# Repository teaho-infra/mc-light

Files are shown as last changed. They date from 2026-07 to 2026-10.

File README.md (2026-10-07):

# mc-light

感知 Claude Code agent 状态的麦当劳金拱门 "M" 指示灯。agent 干活时 M 常亮金色,等待授权时闪烁,空闲时熄灭。USB 连接,跨平台(Windows / Ubuntu)。

## 效果

| agent 状态 | 灯效 |
|---|---|
| 干活中(用户提交 / 工具执行完) | 金色常亮 |
| 等待授权(Notification) | 金色闪烁(亮 0.5s / 灭 0.5s) |
| 空闲(Stop / SessionEnd) | 熄灭 |

## 项目结构

```
mc-light/
├── firmware/            # XIAO RP2040 端 CircuitPython 固件
│   ├── boot.py          # 开启第二路 USB CDC 数据串口
│   └── code.py          # 主循环:读串口单字符,驱动 NeoPixel,45s 看门狗
├── host/                # 电脑端脚本
│   ├── mc_light.py      # hook 入口:按 VID 找串口,发送命令字符
│   ├── requirements.txt # 依赖(pyserial)
│   └── tests/           # pytest 单元测试(find_light_port / main 等)
├── hardware/            # 3D 打印外壳
│   ├── generate_m_shell.py  # 参数化生成显示器侧贴灯盒 STL
│   ├── test_generate_m_shell.py
│   └── *.stl / *.3mf    # 生成的打印件与切片文件
├── hooks/               # Claude Code hooks 配置样例
│   ├── settings.ubuntu.json
│   └── settings.windows.json
├── docs/                # 设计文档与迭代方案(superpowers specs/plans)
├── server.sh            # 辅助脚本
└── README.md
```

## 硬件

- Seeed XIAO RP2040 ×1(板载 NeoPixel RGB 灯)
- USB-C 数据线 ×1(必须是数据线,非纯充电线)
- 3D 打印:显示器右侧贴装方形灯盒。后壳容纳 XIAO RP2040,USB-C 从底部往上插入;前盖用红色半透明区域 + 黄色半透明 M 区域多色打印,两者正面齐平并透光。

### 3D 打印件

`hardware/generate_m_shell.py` 生成显示器侧贴灯盒:

| 文件 | 用途 |
|---|---|
| `hardware/mc_light_monitor_back.stl` | 后壳,背面贴双面胶,内部放 XIAO RP2040 |
| `hardware/mc_light_monitor_front_red.stl` | 前盖红色半透明区域 |
| `hardware/mc_light_monitor_front_M.stl` | 前盖黄色半透明 M 区域 |
| `hardware/mc_light_monitor_front_assembled.stl` | 前盖红黄区域装配预览 |
| `hardware/mc_light_monitor_assembled.stl` | 整体装配预览 |

多色打印时,把红色区域和黄色 M 区域作为同一个前盖的两个颜色对象合并打印。前盖正面齐平,M 不突出。装配时将 XIAO RP2040 放进后壳,USB-C 端朝下,确认线缆能从底部向上插入,再扣上前盖并把后壳贴到显示器右侧。

## 安装

### 1. 固件(板子端)
1. 给 XIAO RP2040 刷 CircuitPython。
2. 把 `neopixel.mpy` 放进 `CIRCUITPY/lib/`。
3. 复制 `firmware/boot.py`、`firmware/code.py` 到 `CIRCUITPY` 根目录,重新插拔。

### 2. 主机脚本(电脑端)
- **Windows(推荐)**:`host/mc_light.py` 用纯标准库(winreg + ctypes),不需要装任何包。
- **Ubuntu / WSL**:需要 pyserial:
  ```
  pip install -r host/requirements.txt
  ```
自测:`python3 host/mc_light.py on`(不插灯也应静默退出、返回 0)。

### 3. Claude Code / CodeBuddy hooks
把 `hooks/settings.ubuntu.json`(Ubuntu)或 `hooks/settings.windows.json`(Windows)的内容合并进你的 hook 配置文件,并把命令里的路径改成你的绝对路径。

- **Ubuntu**(Claude Code):合并进 `~/.claude/settings.json`。
- **Windows / CodeBuddy**:合并进 `~/.codebuddy/settings.json`。CodeBuddy 的 hook 命令在 Windows 上**强制用 Git Bash 执行**,配置里已用 `$CODEBUDDY_PROJECT_DIR` 环境变量定位项目,路径含空格也能正确处理。Windows 上直接用系统 `python`(已加入 PATH);若你的 python 不在 PATH,把 `python` 换成绝对路径并在两侧加引号,例如:
  ```
  "C:\\Users\\you\\AppData\\Local\\Programs\\Python\\Python312\\python.exe" "$CODEBUDDY_PROJECT_DIR/host/mc_light.py" on
  ```

> 提示:直接运行 `host/mc_light.py` 即可验证 hook 命令是否正确。CodeBuddy 的 `$CODEBUDDY_PROJECT_DIR` 只在 hook 运行时注入,命令行里手动跑要用真实路径。

## 工作原理

```
Claude Code 事件 → hook 脚本 → USB 串口(单字符 1/2/0)→ XIAO 固件 → RGB 灯
```

- `UserPromptSubmit` → 发 `1`(常亮金,干活中)
- `Notification`(仅 `permission_prompt` 授权请求,matcher 过滤)→ 发 `2`(金色闪烁,等待授权)。普通输入等待(60s 无输入的 `idle_prompt`)不触发闪烁。
- `PostToolUse`(工具执行完,含授权后)→ 发 `1`(恢复常亮)
- `Stop` / `SessionEnd` → 发 `0`(灭,空闲)

### 通信协议

主机与板子之间只有单字节字符命令,无握手、无回包:

| 字符 | 含义 | 固件行为 |
|---|---|---|
| `1` | 常亮 | 金色 (255, 180, 0) 常亮 |
| `2` | 闪烁 | 金色以 0.5s 半周期闪烁 |
| `0` | 熄灭 | 关灯 |
| 其它 | 预留(3-9) | 忽略 |

### 关键设计

- **串口选择**:`boot.py` 用 `usb_cdc.enable(console=True, data=True)` 打开两路 CDC。`host/mc_light.py` 的 `_select_data_port()` 优先 description 里的 "CDC2"/"data" 标记;Windows 上描述没有该文本时,改用 USB 接口号(`MI_00`/`MI_02`)区分——data 口接口号大。**绝不按 COM 号排序**(Windows 的 COM 号不保证顺序,`COM9` 在 `COM10` 前)。无法唯一识别时返回 None 静默退出,可用环境变量 `MC_LIGHT_PORT=COM10` 显式指定。
- **VID 自动匹配**:同时匹配 Raspberry Pi 官方 `0x2E8A` 与 Seeed 自家 `0x2886`,不硬编码端口名;别家 RP2040 板子可把 VID 加进 `XIAO_VIDS`。
- **失败静默**:找不到灯或出错时脚本静默退出、返回 0,绝不影响 Claude Code(`MC_LIGHT_DEBUG=1` 时才把错误打到 stderr)。
- **45 秒看门狗**:固件侧常亮或闪烁超时未更新自动熄灭——兜住 Ctrl+C 中断(Claude Code 中断不触发 Stop hook)。
- **非阻塞读**:固件 `serial.timeout = 0`,主循环 50ms 一拍,同时处理闪烁翻转与看门狗。

## 测试

```
pytest host/tests
pytest hardware/test_generate_m_shell.py
```

## 验收

插上灯用 Claude Code:发一句话 → M 常亮金;触发需要授权的操作 → M 闪烁;点允许 → M 恢复常亮;答完 → M 灭。不插灯时 Claude Code 完全正常。

## 排错

脚本作为 hook 时默认静默失败,不会吵到 Claude Code。手动排查加环境变量:

```
MC_LIGHT_DEBUG=1 python3 host/mc_light.py on
```

出错会打到 stderr。常见两坑:

### Ubuntu:`Permission denied: '/dev/ttyACM*'`

`/dev/ttyACM*` 属 `root:dialout`,普通用户默认没这个组。修复:

```
sudo usermod -aG dialout $USER
```

**必须重新登录一次**(注销再登录,或重启),`groups` 里才会出现 `dialout`,当前 shell 里不重登怎么试都还是 permission denied。Windows 没这个问题。

### 找不到设备 / VID 不匹配

Seeed 版 XIAO RP2040 的 USB VID 是 `0x2886`,不是 Raspberry Pi 官方的 `0x2E8A`。脚本现在两个 VID 都匹配。如果是别家 RP2040 板子(VID 不在这两个里),用下面命令看真实 VID,再加到 `host/mc_light.py` 的 `XIAO_VIDS`:

```
python3 -c "from serial.tools import list_ports; [print(p.device, hex(p.vid) if p.vid else None, p.description) for p in list_ports.comports()]"
```

Windows 上(无 pyserial)看 COM 口:

```
powershell -NoProfile -Command "Get-PnpDevice -PresentOnly | Where-Object { $_.Class -eq 'Ports' } | Format-Table FriendlyName,InstanceId -AutoSize"
```

### Windows 串口枚举与显式指定

- 板子会枚举出两个 COM 口:**console(REPL)口**和 **data 口**。脚本选 data 口。
- 若自动识别失败或插了多块同厂商板子,用环境变量显式指定:
  ```
  MC_LIGHT_PORT=COM10 MC_LIGHT_DEBUG=1 python host/mc_light.py on
  ```
- 找到的口不对时(例如灯没反应),`MC_LIGHT_DEBUG=1` 会在 stderr 打印错误;也可以逐口试:分别 `MC_LIGHT_PORT=COMx` 跑 `on`,灯亮的那口就是 data 口。

如果看到板子只出一个 COM 口(应该有两个:控制台 + 数据),说明 `firmware/boot.py` 没生效——检查它是否已复制到 `CIRCUITPY` 根目录并**断电重插**过一次(boot.py 只在上电时执行)。

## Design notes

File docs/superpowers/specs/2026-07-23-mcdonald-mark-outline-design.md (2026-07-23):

# McDonald Mark Outline Correction

## Goal

Correct the yellow mark in the monitor front-panel STL so its silhouette matches
`hardware/McDonald.jpeg` while preserving the existing 24 mm nominal width,
1.2 mm flush front-panel thickness, split-color STL workflow, and case geometry.

## Root Cause

The current `m_polygon()` buffers three center lines with a uniform stroke width.
That construction makes the arch crowns too thick, the arches too tall and
narrow, the outside shoulders too steep, and the center foot too short. A
normalized raster comparison against the supplied reference has an
intersection-over-union score of only 0.6409.

## Selected Design

Build one symmetric filled polygon from explicit outer and inner cubic Bezier
curves. The outer contour controls the overall shoulders and arch crowns. The
inner contour independently controls the two counters and center valley, so
stroke thickness can vary like the reference instead of being imposed by a
uniform buffer.

Keep the outline parameterized by `width / M_WIDTH`. Center the final polygon
from its actual bounds. Do not load the JPEG at generation time; the generated
STL must remain deterministic and self-contained.

## Alternatives Considered

- Trace the JPEG into a long fixed point list. This gives high fidelity but is
  difficult to understand, tune, and review.
- Extract the yellow mask from the JPEG every time the STL is generated. This
  keeps the raster appearance but couples production output to image-processing
  thresholds and an external asset.
- Fit independent Bezier contours. This gives comparable visual fidelity with a
  small, deterministic, maintainable geometry definition. This is selected.

## Verification

- Add a failing test for the reference width-to-height ratio.
- Add a failing test for reference-relative crown, valley, and foot positions.
- Add a failing raster-similarity test using a compact set of normalized
  reference silhouette samples rather than loading the JPEG in production.
- Retain existing volume, alignment, size, and assembly tests.
- Regenerate all affected STL outputs and confirm they are watertight.
- Render a normalized before/after overlay for visual inspection.

## Scope

Only the yellow mark geometry, its focused tests, and generated STL artifacts
change. The back shell, front thickness, red/yellow split, box dimensions, and
USB/XIAO geometry remain unchanged.

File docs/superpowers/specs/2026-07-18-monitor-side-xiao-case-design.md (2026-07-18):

# 显示器侧贴 XIAO 麦当劳灯盒设计文档

**日期**: 2026-07-18
**状态**: 设计已确认,待实现计划

## 1. 概述

本次改造将现有桌面底座式 mc-light 3D 打印件,重新建模为一个贴在电脑显示屏右侧的方形灯盒。灯盒内放入 Seeed XIAO RP2040,使用板载 NeoPixel 作为光源。USB-C 口朝下,线缆从盒子底部向上插入。

外观为麦当劳红黄色标志:前盖为红色半透明面板,黄色半透明 M 标记与前盖一体多色打印,正面齐平、不突出、不下陷。红色前盖和黄色 M 都透光。

## 2. 目标

- 方形盒体,适合用双面胶贴在显示器右边框或右侧背面。
- 容纳 Seeed XIAO RP2040,板子固定后 USB-C 端朝下。
- 底部开口允许 USB-C 插头从下往上插入。
- 前盖使用多色打印形成红色背景和黄色 M,两者都尽可能薄以便透光。
- 前盖正面平整,黄色 M 不做凸起装饰。
- 输出可打印 STL/3MF 文件,并保留组装预览文件。

## 3. 非目标

- 不做桌面底座。
- 不做外接灯珠、焊接结构或额外电路。
- 不做螺丝固定;优先使用压合、卡扣或少量胶合。
- 不追求防水、防摔或长期户外使用。

## 4. 机械结构

### 4.1 总体结构

打印件分为两大结构:

| 部件 | 功能 |
|---|---|
| 后壳 | 承载 XIAO RP2040,提供贴屏平面、侧壁和底部 USB-C 开口 |
| 一体式多色前盖 | 半透明红色面板 + 半透明黄色 M 标记,负责视觉外观和透光 |

外形建议约 `38 x 38 x 14 mm`,实现时允许根据板腔、壁厚、USB-C 插头 clearance 微调。盒体保持方形观感,边角只做小圆角或倒角以改善打印手感。

### 4.2 后壳

后壳为浅盒结构:

- 背面完全平整,预留给双面胶或纳米胶贴在显示器右侧。
- 内部竖向放置 XIAO RP2040,板子长边沿盒体竖直方向。
- USB-C 端朝下,对准底部开口。
- 板载 NeoPixel 朝向前盖,中间留扩散距离,避免灯珠贴脸造成强热点。
- 内壁优先使用浅色或反光打印材料;如果漏光明显,可改为不透光材料。

后壳内部应包含简单定位结构:

- 板腔按 XIAO RP2040 约 `21 x 17.8 mm` 外形留间隙。
- 用低矮边框、压片或限位柱限制板子晃动。
- 不压迫 USB-C 连接器、BOOT/RESET 按键或板上元件。
- 保留手动取出板子的可能性,除非后续实现中明确选择胶固定。

### 4.3 USB-C 底部开口

USB-C 从底部往上插入:

- 开口位于后壳底边中心。
- 宽度和高度应同时兼容 XIAO 板载 USB-C 母座及常见 USB-C 插头外壳。
- 插头插入后,线缆自然向下离开盒体。
- 开口不能削弱后壳底边到影响强度;必要时在开口两侧保留加强肋。

### 4.4 一体式多色透光前盖

前盖是单个几何件,但包含两个多色区域:

- 红色半透明背景区域。
- 黄色半透明 M 标记区域。

设计要求:

- 正面完全齐平。
- M 不突出、不下陷。
- 红色前盖和黄色 M 都透光。
- 厚度尽可能薄,目标 `1.0-1.5 mm`。
- M 区域和红色区域共享同一前盖厚度,依靠材料颜色区分标志。
- 前盖背面可增加浅定位边或压合边,但不能让正面产生明显台阶。

如果 STL 不适合表达多材料区域,实现时可同时输出:

- 一个装配预览模型。
- 红色区域模型。
- 黄色 M 区域模型。

多色切片软件中将红色区域和黄色区域作为同一前盖的不同颜色对象进行合并打印。

## 5. 装配方式

推荐装配顺序:

1. 将 XIAO RP2040 放入后壳,USB-C 端朝下。
2. 确认 USB-C 线可从底部向上插入并正常连接。
3. 将多色前盖压入或扣入后壳。
4. 在后壳背面贴双面胶。
5. 将灯盒贴在显示器右边框或右侧背面。

前盖与后壳之间建议使用压合结构。默认间隙取 `0.3-0.5 mm`,实际值按打印机精度调整。

## 6. 打印建议

- 前盖红色区域:红色半透明 PLA/PETG。
- 前盖 M 区域:黄色半透明 PLA/PETG。
- 后壳:红色、不透光黑色、白色或其他材料均可;若希望整体发光更均匀,后壳内侧可选白色。
- 前盖朝下打印可获得更平整的正面,但需要避免 M/红色边界处产生明显首层污染。
- 若透光不足,优先减薄前盖;若热点明显,优先增加灯珠到前盖距离或在前盖背面加轻微磨砂处理。

## 7. 输出文件

实现时更新 `hardware/generate_m_shell.py`,输出新的模型文件:

| 文件 | 用途 |
|---|---|
| `mc_light_monitor_back.stl` | 后壳打印件 |
| `mc_light_monitor_front_red.stl` | 前盖红色区域 |
| `mc_light_monitor_front_M.stl` | 前盖黄色 M 区域 |
| `mc_light_monitor_front_assembled.stl` | 前盖多色装配预览 |
| `mc_light_monitor_assembled.stl` | 整体装配预览 |

如实现工具链支持 3MF 多材料导出,可额外输出一个多材料前盖 3MF;STL 拆分仍作为通用交付物保留。

## 8. 验收标准

- XIAO RP2040 能放入后壳且不会明显晃动。
- USB-C 插头能从底部向上插入,线缆向下走线。
- 后壳背面平整,适合贴胶。
- 前盖正面为红底黄 M,表面齐平。
- 红色区域和黄色 M 区域都能透出板载 NeoPixel 的光。
- 模型导出成功,主要 STL 为 watertight 或符合切片软件可修复范围。

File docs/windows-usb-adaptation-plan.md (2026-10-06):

# Windows USB 连接适配计划

## 当前结论

项目已有 Windows hook 样例，`pyserial` 也支持 Windows COM 端口，因此通信方案可用于 Windows；但目前不能认为 Windows USB 连接已可靠适配，也没有 Windows 真机验收记录。

主要缺口：

1. `host/mc_light.py` 优先凭端口描述中的 `CDC2`/`data` 找数据口；没有这些文本时，按 `device` 字符串排序并取最后一个。Windows 的两个 CDC COM 号不保证相邻或按 console、data 顺序分配；字符串排序还会把 `COM9` 排在 `COM10` 后。此时可能写入 REPL 控制台口，灯不会响应。
2. 仅按 VID (`0x2E8A`/`0x2886`) 过滤，连接多块同厂商板子时可能选中另一块设备。
3. `hooks/settings.windows.json` 使用占位路径且没有引号；路径含空格时命令可能执行失败。它也缺少与 Ubuntu 样例一致的 `SessionEnd` 熄灯 hook。
4. 现有测试用模拟 COM 口验证基础流程，但没有覆盖 COM 号乱序、描述缺失、多设备、路径含空格，也没有 Windows + XIAO RP2040 实机测试。

## 实施步骤

1. **采集 Windows 枚举信息**：在 Windows 上接入烧录了本项目 `boot.py`/`code.py` 的 XIAO RP2040，运行 `python -m serial.tools.list_ports -v`，记录两路端口的 `device`、VID/PID、`interface`、`description`、`hwid`、`serial_number` 和 `location`。分别验证 Seeed 和 Raspberry Pi VID（若有对应硬件）。
2. **确定数据口识别规则**：优先使用可验证的 USB 接口号或固件设置的独立接口名称，结合 VID/PID、序列号/位置锁定目标板。不要把 COM 号大小当成接口顺序。若元数据不足或有多个候选口，返回“无法确定”，并提供显式端口配置（例如环境变量 `MC_LIGHT_PORT=COM10`）；不要猜测一个口。
3. **修改主机脚本和测试**：让 `find_light_port()` 采用上述规则。补充 COM9/COM10、非连续及反序 COM 号、描述为空、多块板、指定端口不存在等用例。保持 hook 失败时静默返回 0，并在 `MC_LIGHT_DEBUG=1` 下给出候选口和判定原因。
4. **修正 Windows hook 与安装文档**：给 Python 和脚本绝对路径加可靠的命令行引号，添加 `SessionEnd`，说明在 Windows 本机 Python 环境安装 `pyserial`、验证 COM 端口和启用调试的方法。说明 WSL 与 Windows 本机的端口访问需要分别配置。
5. **实机验收**：在 Windows 10/11 上断电重插板子，确认出现 console/data 两个 COM 口；运行 `on`、`wait`、`off`，分别看到常亮、闪烁、熄灭。再通过 Claude Code 触发 `UserPromptSubmit`、`Notification`、`PostToolUse`、`Stop`、`SessionEnd`。重复测试 COM 号变化、路径含空格、无设备及多设备场景，确认不会向 REPL 口写入命令。

## 完成标准

- Windows 真机上自动识别数据口，或在无法唯一识别时用显式端口配置成功连接。
- 所有上述 hook 事件触发正确灯效；断开设备或端口忙时 Claude Code 正常运行。
- Windows 相关自动化测试通过，README 给出可复现的安装、诊断和验收步骤。

参考：[CircuitPython USB CDC 文档](https://docs.circuitpython.org/en/latest/shared-bindings/usb_cdc/)（Windows COM 口顺序不保证）、[pySerial 端口枚举文档](https://pyserial.readthedocs.io/en/latest/tools.html)（端口元数据与顺序）。

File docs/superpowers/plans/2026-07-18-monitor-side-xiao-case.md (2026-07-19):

# Monitor-Side XIAO Case Implementation Plan

> **For agentic workers:** REQUIRED SUB-SKILL: Use superpowers:subagent-driven-development (recommended) or superpowers:executing-plans to implement this plan task-by-task. Steps use checkbox (`- [ ]`) syntax for tracking.

**Goal:** Replace the current desktop-base STL generator with a monitor-side square case for Seeed XIAO RP2040, including a flat multi-color translucent red/yellow front cover.

**Architecture:** Keep `hardware/generate_m_shell.py` as the single CAD generator and expose small pure functions for dimensions, McDonald's-style M geometry, back shell, front red area, front yellow M area, and assembly previews. Add Python tests that inspect mesh bounds, watertightness, and color-part alignment without needing a slicer. Export split STL files so multi-color slicers can merge the red and yellow front cover parts into one flush front face.

**Tech Stack:** Python 3, `trimesh`, `shapely`, `numpy`, pytest.

## Global Constraints

- 方形盒体,适合用双面胶贴在显示器右边框或右侧背面。
- 容纳 Seeed XIAO RP2040,板子固定后 USB-C 端朝下。
- 底部开口允许 USB-C 插头从下往上插入。
- 前盖使用多色打印形成红色背景和黄色 M,两者都尽可能薄以便透光。
- 前盖正面平整,黄色 M 不做凸起装饰。
- 红色前盖和黄色 M 都透光。
- 前盖厚度目标 `1.0-1.5 mm`。
- 不做桌面底座。
- 不做外接灯珠、焊接结构或额外电路。
- 不做螺丝固定;优先使用压合、卡扣或少量胶合。
- 输出 `mc_light_monitor_back.stl`, `mc_light_monitor_front_red.stl`, `mc_light_monitor_front_M.stl`, `mc_light_monitor_front_assembled.stl`, and `mc_light_monitor_assembled.stl`.

---

## File Structure

- Modify `hardware/generate_m_shell.py`: replace the old M lightbox + desktop base generator with the monitor-side case generator. Keep all dimensions centralized at top-level constants. Provide importable builder functions for tests.
- Create `hardware/test_generate_m_shell.py`: unit tests for critical dimensions, front-cover flush alignment, USB bottom opening, and exported file names.
- Modify `README.md`: update the 3D printing section so it describes the monitor-side box, two-part physical structure, split front STL files, and bottom-up USB-C insertion.
- Generated by running `python3 hardware/generate_m_shell.py`: `hardware/mc_light_monitor_back.stl`, `hardware/mc_light_monitor_front_red.stl`, `hardware/mc_light_monitor_front_M.stl`, `hardware/mc_light_monitor_front_assembled.stl`, `hardware/mc_light_monitor_assembled.stl`.

---

### Task 1: Add CAD Geometry Tests

**Files:**
- Create: `hardware/test_generate_m_shell.py`
- Test: `hardware/test_generate_m_shell.py`

**Interfaces:**
- Consumes: existing module import path `hardware/generate_m_shell.py`.
- Produces: tests expecting `BOX_W`, `BOX_H`, `BOX_D`, `FRONT_T`, `XIAO_W`, `XIAO_H`, `USB_OPEN_W`, `USB_OPEN_H`, `OUTPUTS`, `build_back_shell()`, `build_front_parts()`, `build_front_assembled()`, and `build_monitor_assembled()`.

- [x] **Step 1: Write the failing tests**

Create `hardware/test_generate_m_shell.py`:

```python
import importlib.util
from pathlib import Path

import pytest

MODULE_PATH = Path(__file__).with_name("generate_m_shell.py")

def load_generator():
    spec = importlib.util.spec_from_file_location("generate_m_shell", MODULE_PATH)
    module = importlib.util.module_from_spec(spec)
    spec.loader.exec_module(module)
    return module

def bounds_size(mesh):
    bounds = mesh.bounds
    return bounds[1] - bounds[0]

def test_front_parts_are_flush_and_thin():
    gen = load_generator()

    red, yellow = gen.build_front_parts()

    assert red.is_volume
    assert yellow.is_volume
    assert pytest.approx(red.bounds[:, 2].tolist(), abs=0.01) == [0.0, gen.FRONT_T]
    assert pytest.approx(yellow.bounds[:, 2].tolist(), abs=0.01) == [0.0, gen.FRONT_T]
    assert 1.0 <= gen.FRONT_T <= 1.5

def test_front_assembled_matches_square_face_size():
    gen = load_generator()

    front = gen.build_front_assembled()
    sx, sy, sz = bounds_size(front)

    assert pytest.approx(sx, abs=0.05) == gen.BOX_W
    assert pytest.approx(sy, abs=0.05) == gen.BOX_H
    assert pytest.approx(sz, abs=0.01) == gen.FRONT_T

def test_back_shell_has_bottom_usb_opening_and_xiao_clearance():
    gen = load_generator()

    back = gen.build_back_shell()
    sx, sy, sz = bounds_size(back)

    assert back.is_volume
    assert pytest.approx(sx, abs=0.05) == gen.BOX_W
    assert pytest.approx(sy, abs=0.05) == gen.BOX_H
    assert pytest.approx(sz, abs=0.05) == gen.BOX_D - gen.FRONT_T
    assert gen.BOARD_POCKET_W >= gen.XIAO_W + 1.0
    assert gen.BOARD_POCKET_H >= gen.XIAO_H + 1.0
    assert gen.USB_OPEN_W >= 12.0
    assert gen.USB_OPEN_H >= 8.0

def test_assembly_preview_contains_back_and_front_depth():
    gen = load_generator()

    assembled = gen.build_monitor_assembled()
    sx, sy, sz = bounds_size(assembled)

    assert pytest.approx(sx, abs=0.05) == gen.BOX_W
    assert pytest.approx(sy, abs=0.05) == gen.BOX_H
    assert pytest.approx(sz, abs=0.05) == gen.BOX_D

def test_output_names_match_spec():
    gen = load_generator()

    assert [name for name, _builder in gen.OUTPUTS] == [
        "mc_light_monitor_back.stl",
        "mc_light_monitor_front_red.stl",
        "mc_light_monitor_front_M.stl",
        "mc_light_monitor_front_assembled.stl",
        "mc_light_monitor_assembled.stl",
    ]
```

- [x] **Step 2: Run tests to verify they fail**

Run: `python3 -m pytest hardware/test_generate_m_shell.py -v`

Expected: FAIL with missing attributes such as `BOX_W` or `build_back_shell`.

- [x] **Step 3: Commit failing tests**

```bash
git add hardware/test_generate_m_shell.py
git commit -m "test: cover monitor case generator geometry"
```

---

### Task 2: Implement Monitor-Side Case Generator

**Files:**
- Modify: `hardware/generate_m_shell.py`
- Test: `hardware/test_generate_m_shell.py`

**Interfaces:**
- Consumes: tests from Task 1.
- Produces:
  - `build_back_shell() -> trimesh.Trimesh`
  - `build_front_parts() -> tuple[trimesh.Trimesh, trimesh.Trimesh]`
  - `build_front_assembled() -> trimesh.Trimesh`
  - `build_monitor_assembled() -> trimesh.Trimesh`
  - `OUTPUTS: list[tuple[str, Callable[[], trimesh.Trimesh]]]`

- [x] **Step 1: Replace the generator docstring and imports**

At the top of `hardware/generate_m_shell.py`, use:

```python
"""生成 mc-light 的显示器侧贴 3D 打印模型。

输出 STL(写到本脚本同目录):
  mc_light_monitor_back.stl              —— 后壳:贴屏平背 + XIAO 腔 + 底部 USB-C 开口
  mc_light_monitor_front_red.stl         —— 多色前盖红色半透明区域
  mc_light_monitor_front_M.stl           —— 多色前盖黄色半透明 M 区域
  mc_light_monitor_front_assembled.stl   —— 前盖红黄区域装配预览
  mc_light_monitor_assembled.stl         —— 整体装配预览

所有尺寸单位 mm,集中在参数区,按需修改后重跑即可。
运行:python3 hardware/generate_m_shell.py
"""
import os

import numpy as np
import trimesh
from shapely.affinity import translate as shp_translate
from shapely.geometry import MultiPolygon, Polygon, box as shp_box
```

- [x] **Step 2: Define dimensions and helpers**

Replace the old parameter block and helper functions with:

```python
# ----------------------------- 参数区 -----------------------------
BOX_W = 38.0
BOX_H = 38.0
BOX_D = 14.0
FRONT_T = 1.2
BACK_D = BOX_D - FRONT_T
WALL_T = 2.0
PRESS_CLEAR = 0.35
LIP_T = 1.0
LIP_D = 1.2

XIAO_W = 17.8
XIAO_H = 21.0
BOARD_POCKET_W = XIAO_W + 1.4
BOARD_POCKET_H = XIAO_H + 1.4
BOARD_RAIL_T = 1.0
BOARD_RAIL_H = 1.2

USB_OPEN_W = 13.5
USB_OPEN_H = 8.5
USB_OPEN_D = BACK_D + 0.6

M_WIDTH = 24.0
ARCH_R = M_WIDTH / 4.0
LEG_H = 12.0
M_HEIGHT = LEG_H + ARCH_R
CURVE_STEPS = 120

OUT_DIR = os.path.dirname(os.path.abspath(__file__))
ENGINE = "manifold"

def largest(poly):
    """buffer 后若变成 MultiPolygon,取面积最大的那块。"""
    if isinstance(poly, MultiPolygon):
        return max(poly.geoms, key=lambda g: g.area)
    return poly

def make_box(extents, center):
    mesh = trimesh.creation.box(extents=extents)
    mesh.apply_translation(center)
    return mesh
```

- [x] **Step 3: Add M and front-cover builders**

Add these functions after the helpers:

```python
def m_polygon(width=M_WIDTH):
    """返回居中的麦当劳风格 M 填充多边形,位于 XY 平面。"""
    arch_r = width / 4.0
    leg_h = LEG_H * (width / M_WIDTH)
    cx1 = arch_r
    cx2 = width - arch_r
    xs = np.linspace(0.0, width, CURVE_STEPS)
    h1 = np.sqrt(np.clip(arch_r**2 - (xs - cx1) ** 2, 0, None))
    h2 = np.sqrt(np.clip(arch_r**2 - (xs - cx2) ** 2, 0, None))
    top = leg_h + np.maximum(h1, h2)
    pts = [(0.0, 0.0)]
    pts += [(float(x), float(y)) for x, y in zip(xs, top)]
    pts += [(width, 0.0)]
    poly = Polygon(pts)
    return shp_translate(poly, xoff=-width / 2.0, yoff=-poly.bounds[3] / 2.0)

def build_front_parts():
    """返回红色背景区域和黄色 M 区域;两者 z 范围完全一致,正面齐平。"""
    face = shp_box(-BOX_W / 2.0, -BOX_H / 2.0, BOX_W / 2.0, BOX_H / 2.0)
    m_mark = m_polygon()
    red_area = face.difference(m_mark)

    red = trimesh.creation.extrude_polygon(red_area, height=FRONT_T)
    yellow = trimesh.creation.extrude_polygon(m_mark, height=FRONT_T)
    return red, yellow

def build_front_assembled():
    red, yellow = build_front_parts()
    return trimesh.util.concatenate([red, yellow])
```

- [x] **Step 4: Add back-shell builder**

Add:

```python
def build_back_shell():
    """后壳:背面平整,正面开口,底部 USB-C 开口,内部有 XIAO 限位结构。"""
    outer = make_box([BOX_W, BOX_H, BACK_D], [0, 0, BACK_D / 2.0])
    inner = make_box(
        [BOX_W - 2 * WALL_T, BOX_H - 2 * WALL_T, BACK_D - WALL_T],
        [0, 0, WALL_T + (BACK_D - WALL_T) / 2.0],
    )
    usb_cut = make_box(
        [USB_OPEN_W, WALL_T * 3.0, USB_OPEN_H],
        [0, -BOX_H / 2.0, USB_OPEN_H / 2.0],
    )
    shell = trimesh.boolean.difference([outer, inner, usb_cut], engine=ENGINE)

    rail_y_gap = BOARD_POCKET_W / 2.0 + BOARD_RAIL_T / 2.0
    rail_z = WALL_T + BOARD_POCKET_H / 2.0
    left_rail = make_box(
        [BOARD_RAIL_T, BOARD_POCKET_H, BOARD_RAIL_H],
        [-rail_y_gap, 0, rail_z],
    )
    right_rail = make_box(
        [BOARD_RAIL_T, BOARD_POCKET_H, BOARD_RAIL_H],
        [rail_y_gap, 0, rail_z],
    )
    bottom_stop = make_box(
        [BOARD_POCKET_W + 2 * BOARD_RAIL_T, BOARD_RAIL_T, BOARD_RAIL_H],
        [0, -BOARD_POCKET_H / 2.0, rail_z],
    )
    return trimesh.util.concatenate([shell, left_rail, right_rail, bottom_stop])
```

During implementation, orient dimensions so global `X` is left-right, `Y` is vertical on the displayed face, and `Z` is depth from front to back. The bottom USB opening is at negative `Y`.

- [x] **Step 5: Add assembly builders and outputs**

Add:

```python
def build_monitor_assembled():
    back = build_back_shell()
    front = build_front_assembled()
    front.apply_translation([0, 0, BACK_D])
    return trimesh.util.concatenate([back, front])

OUTPUTS = [
    ("mc_light_monitor_back.stl", build_back_shell),
    ("mc_light_monitor_front_red.stl", lambda: build_front_parts()[0]),
    ("mc_light_monitor_front_M.stl", lambda: build_front_parts()[1]),
    ("mc_light_monitor_front_assembled.stl", build_front_assembled),
    ("mc_light_monitor_assembled.stl", build_monitor_assembled),
]
```

- [x] **Step 6: Replace `main()`**

Use:

```python
def main():
    for name, builder in OUTPUTS:
        mesh = builder()
        path = os.path.join(OUT_DIR, name)
        mesh.export(path)
        wt = getattr(mesh, "is_watertight", None)
        print(
            f"{name}: {len(mesh.vertices)} verts, {len(mesh.faces)} faces, "
            f"watertight={wt}"
        )

    print("完成。后壳单独打印;前盖红色区域和黄色 M 区域作为多色同层前盖合并打印。")

if __name__ == "__main__":
    main()
```

- [x] **Step 7: Run geometry tests**

Run: `python3 -m pytest hardware/test_generate_m_shell.py -v`

Expected: PASS for all five tests.

- [x] **Step 8: Run generator and inspect exported meshes**

Run: `python3 hardware/generate_m_shell.py`

Expected output includes all five file names:

```text
mc_light_monitor_back.stl:
mc_light_monitor_front_red.stl:
mc_light_monitor_front_M.stl:
mc_light_monitor_front_assembled.stl:
mc_light_monitor_assembled.stl:
完成。后壳单独打印;前盖红色区域和黄色 M 区域作为多色同层前盖合并打印。
```

- [x] **Step 9: Commit generator changes and generated STLs**

```bash
git add hardware/generate_m_shell.py hardware/mc_light_monitor_back.stl hardware/mc_light_monitor_front_red.stl hardware/mc_light_monitor_front_M.stl hardware/mc_light_monitor_front_assembled.stl hardware/mc_light_monitor_assembled.stl
git commit -m "feat: generate monitor-side xiao case"
```

---

### Task 3: Update Hardware Documentation

**Files:**
- Modify: `README.md`
- Test: `README.md`

**Interfaces:**
- Consumes: output file names from Task 2.
- Produces: user-facing printing and assembly instructions matching the new monitor-side model.

- [x] **Step 1: Update the hardware bullet**

In `README.md`, replace:

```markdown
- 3D 打印:半透明金拱门 M 外壳(约 6cm)+ 底座,PLA 半透明/白色。M 罩在板载灯珠上方,靠打印件壁厚做光线漫射。
```

with:

```markdown
- 3D 打印:显示器右侧贴装方形灯盒。后壳容纳 XIAO RP2040,USB-C 从底部往上插入;前盖用红色半透明区域 + 黄色半透明 M 区域多色打印,两者正面齐平并透光。
```

- [x] **Step 2: Add a 3D printing subsection after the hardware list**

Insert:

```markdown
### 3D 打印件

`hardware/generate_m_shell.py` 生成显示器侧贴灯盒:

| 文件 | 用途 |
|---|---|
| `hardware/mc_light_monitor_back.stl` | 后壳,背面贴双面胶,内部放 XIAO RP2040 |
| `hardware/mc_light_monitor_front_red.stl` | 前盖红色半透明区域 |
| `hardware/mc_light_monitor_front_M.stl` | 前盖黄色半透明 M 区域 |
| `hardware/mc_light_monitor_front_assembled.stl` | 前盖红黄区域装配预览 |
| `hardware/mc_light_monitor_assembled.stl` | 整体装配预览 |

多色打印时,把红色区域和黄色 M 区域作为同一个前盖的两个颜色对象合并打印。前盖正面齐平,M 不突出。装配时将 XIAO RP2040 放进后壳,USB-C 端朝下,确认线缆能从底部向上插入,再扣上前盖并把后壳贴到显示器右侧。
```

- [x] **Step 3: Run documentation checks**

Run: `rg -n "桌面底座|mc_light_base|mc_light_M|显示器右侧|mc_light_monitor" README.md hardware/generate_m_shell.py docs/superpowers/specs/2026-07-18-monitor-side-xiao-case-design.md`

Expected: no stale README instruction telling the user to print a desktop base; monitor-side output names appear in README and generator.

- [x] **Step 4: Run full available verification**

Run: `python3 -m pytest hardware/test_generate_m_shell.py -v`

Expected: PASS.

Run: `cd host && python3 -m pytest -v`

Expected: PASS for existing host tests.

- [x] **Step 5: Commit docs**

```bash
git add README.md docs/superpowers/plans/2026-07-18-monitor-side-xiao-case.md
git commit -m "docs: document monitor-side case printing"
```

---

## Self-Review

- Spec coverage: Task 2 implements the back shell, bottom USB-C opening, XIAO pocket, flat translucent red/yellow front cover, split STL outputs, and assembly previews. Task 3 documents printing and assembly. Task 1 verifies key geometry constraints.
- Placeholder scan: no `TBD`, `TODO`, or "implement later" markers are present.
- Type consistency: tests and implementation tasks consistently use `build_back_shell`, `build_front_parts`, `build_front_assembled`, `build_monitor_assembled`, and `OUTPUTS`.

---

## 实施备注(2026-07-19)

- 已按计划实现并提交。提交顺序为 feat(生成器+STL)-> test -> docs,使每个提交都通过测试(测试依赖生成器,故生成器先于测试提交)。
- **Task 2 Step 4 偏差**:计划中限位筋高度公式 `rail_z = WALL_T + BOARD_POCKET_H / 2.0` 算得 13.2,大于 `BACK_D = 12.8`,会让筋凸出后壳前口并使 `sz ≈ BACK_D` 测试失败。已改为 `rail_z = WALL_T + BOARD_RAIL_H / 2.0`(=2.6),筋贴在内腔后壁、落在盒内 z∈[2.0, 3.2]。
- **Task 3 Step 4 已知问题(非本次范围)**:`host/tests/test_mc_light.py::test_find_light_port_returns_matching_device` 在 HEAD 即失败——测试 mock `SimpleNamespace(vid, device)` 缺少生产代码 `host/mc_light.py:22` 读取的 `description`/`interface` 属性。`host/` 未被本次改动触及,留待单独修复。

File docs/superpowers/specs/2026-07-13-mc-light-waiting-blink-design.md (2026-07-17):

# mc-light 多状态区分设计:等待授权闪烁

**日期**:2026-07-13
**状态**:已批准设计,待编写实现计划
**关联**:在 [2026-07-09 基础设计](2026-07-09-mc-light-design.md) 之上扩展

## 1. 概述

在现有两态(干活中=常亮金 / 空闲=灭)之上,新增第三态**"等待授权"=金色闪烁**。当 Claude Code 需要用户点允许(权限请求)时,M 灯从常亮切为闪烁,提示"在等你";授权后恢复常亮,回合结束后熄灭。

这用掉原设计预留的协议位 `2`,协议保持向前兼容(老固件忽略 `2`)。

## 2. 目标与非目标

### 目标
- 区分三态:干活中 / 等待授权 / 空闲,且"等待授权"用闪烁明显区别于常亮
- 授权后灯自动恢复常亮,直到回合结束才灭
- 沿用现有架构:hook 短命脚本 → 单字符 → 固件自持状态
- 硬件、3D 打印件、设备发现/静默失败逻辑一律不动

### 非目标(YAGNI)
- 呼吸/渐变闪烁(本次用硬切换亮灭,最简单)
- 更多状态颜色(出错、完成提示等,暂不做)
- 周期续命看门狗(维持现有 10 分钟兜底)

## 3. 状态与协议

| 状态 | 含义 | 协议字符 | 灯效 |
|---|---|---|---|
| 干活中 | agent 正在跑 | `1` | 常亮金 |
| 等待授权 | 需要用户点允许 | `2` | 金色闪烁(亮 0.5s / 灭 0.5s,周期 1s) |
| 空闲 | 回合结束 | `0` | 灭 |

- 单字符 ASCII,沿用原协议。`2` 为原设计预留位。
- 未知字符固件仍忽略、不崩溃 —— 向前兼容不变。

## 4. 事件映射(Claude Code hooks)

| 事件 | 发送 | 时机 | 参数 |
|---|---|---|---|
| `UserPromptSubmit` | `1` | 用户提交输入,agent 开始干活 | `on` |
| `Notification` | `2` | 需要授权 → 开始闪烁 | `wait` |
| `PostToolUse` | `1` | 工具执行完(含授权后那次)→ 恢复常亮 | `on` |
| `Stop` | `0` | 回合结束 → 灭 | `off` |

新增 `Notification`、`PostToolUse` 两个 hook。

**设计理由**:
- `Notification` 在 Claude Code 需要用户授权时触发,是"等待授权"的信号源。
- 授权后没有专门的"授权完成"事件把灯切回常亮;改用 `PostToolUse`——被授权阻塞的工具只有在用户允许后才真正执行,执行完触发 `PostToolUse` → 发 `1` 恢复常亮。正常干活时每个工具执行完也发 `1`,但对常亮态幂等、无害。
- `Notification` 不止授权时触发(空闲等待用户回话也可能发),但那种场景通常 `Stop` 已先把灯灭了,影响可忽略。

## 5. 组件改动

### 5.1 固件 `firmware/code.py`(核心改动)
主机脚本是短命的、只发一次字符即退出,因此**闪烁必须由固件自持**。

- 引入当前模式:`OFF` / `SOLID` / `BLINK`。
- 收到 `1` → SOLID(常亮金);`2` → BLINK;`0` → OFF;未知字符忽略。
- BLINK 模式:主循环用 `time.monotonic()` 每 0.5s 翻转灯亮/灭,直到收到 `1` 或 `0` 才停。
- 看门狗:SOLID 与 BLINK 都纳入现有 10 分钟兜底;超时自动灭(等授权时用户走开也会自动熄)。
- 沿用现有 `time.sleep(0.05)` 轮询主循环结构。

### 5.2 主机脚本 `host/mc_light.py`(小改动)
- 在 `COMMANDS` 字典新增 `"wait": b"2"`(现有 `on`→`b"1"`、`off`→`b"0"` 不变)。
- 其余逻辑(按 VID 发现设备、超时、静默失败返回 0)完全不动。

### 5.3 Hook 配置示例 `hooks/settings.{ubuntu,windows}.json`(补充)
- 两份示例各新增 `Notification`(跑 `mc_light.py wait`)与 `PostToolUse`(跑 `mc_light.py on`)两个 hook。
- Ubuntu 用 `python3`,Windows 用 `python`,与现有一致。

### 5.4 文档 `README.md`(补充)
- "工作原理"补上三态与新事件映射;验收步骤补一条"触发授权 → 灯闪 → 允许 → 常亮"。

## 6. 异常处理与边界

沿用原则:hook 脚本永远快速、静默、不报错退出;灯故障绝不干扰 Claude Code。新增边界:

| 情况 | 处理方式 |
|---|---|
| 等授权时用户走开 | BLINK 纳入 10 分钟看门狗,超时自动灭 |
| `Notification` 非授权场景触发 | 灯会闪,但一般 `Stop` 已先灭;可接受 |
| 收到 `2` 的老固件 | 忽略(向前兼容) |
| BLINK 期间收到 `0` | 立即灭,停止闪烁 |

## 7. 测试策略

### 7.1 固件层
- 串口发 `1`/`2`/`0`,肉眼确认 常亮 / 闪烁(亮灭各约 0.5s)/ 灭。
- 发未知字符,确认灯不变、不崩。
- BLINK 态静置,确认约 10 分钟(测试可临时改短)后自动熄灭。
- BLINK 态发 `1` 确认切常亮;发 `0` 确认立即灭。

### 7.2 主机脚本层
- 命令行跑 `mc_light.py wait`,确认灯开始闪。
- 拔灯再跑 `wait`,确认静默退出、返回码 0。

### 7.3 集成层
- 在 Claude Code 里触发一个需授权的操作(如运行命令),确认灯开始闪。
- 点允许,确认灯恢复常亮;回合答完确认灭。

### 验收标准
干活时 M 常亮金;需要授权时 M 闪烁;授权后回到常亮;答完灭。不插灯时 Claude Code 完全正常。

## 8. 交付物

- `firmware/code.py` — 新增 BLINK 模式(核心)
- `host/mc_light.py` — `COMMANDS` 新增 `wait`→`2`
- `hooks/settings.ubuntu.json` / `hooks/settings.windows.json` — 新增 `Notification` + `PostToolUse` 两个 hook
- `README.md` — 更新工作原理与验收

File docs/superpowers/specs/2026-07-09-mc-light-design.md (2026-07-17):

# mc-light 设计文档

**日期**:2026-07-09
**状态**:已批准设计,待编写实现计划

## 1. 概述

mc-light 是一个感知 Claude Code agent 运行状态的实体指示灯。灯做成麦当劳金拱门 "M" 的造型,通过 USB 连接电脑:当 Claude agent 正在干活时,M 亮起金色;agent 空闲(等待用户输入)时,M 熄灭。

面向用户:单片机小白。因此硬件与软件方案均以"最简单、最难失败、免焊接"为首要目标。

## 2. 目标与非目标

### 目标
- agent 运行时亮灯、空闲时灭灯,状态精确
- 免焊接、零常驻服务、代码量最小
- 跨平台:Windows 与 Ubuntu 同一份代码
- 灯设备缺失或故障时,绝不干扰 Claude Code 的正常使用

### 非目标(YAGNI)
- 无线 / WiFi 联网(当前不做,硬件可后期升级)
- 多状态颜色区分(当前只做两态,但协议预留扩展)
- 呼吸灯 / 渐变等需要持续通信的动画效果
- 常驻后台服务

## 3. 硬件

### 主控
**Seeed XIAO RP2040**
- 自带 USB-C 口,直接插电脑
- 板载一颗 NeoPixel RGB 灯珠(WS2812 类型),即照亮 M 的光源,无需外接、无需焊接
- 运行 CircuitPython,改代码如同改 U 盘文件
- RP2040 芯片 USB VID = `0x2E8A`

### 灯效
- 一颗板载 RGB 灯珠整体背光,照亮 3D 打印的半透明金拱门 M
- M 尺寸约 6cm,板载灯珠亮度足够
- 默认颜色:麦当劳金黄色

### 物料清单
| 物件 | 说明 |
|---|---|
| XIAO RP2040 ×1 | 主控 + 板载 RGB 灯 |
| USB-C 数据线 ×1 | 必须是数据线,非纯充电线 |
| 3D 打印:半透明 M 外壳 + 底座 | 用户自行打印,PLA 半透明/白色 |
| (可选)导光/漫射结构 | 靠打印件壁厚实现,使发光均匀 |

后期若要做更大的 M,可外接一颗大灯珠,协议不变。

## 4. 软件架构

### 数据流(单向)
```
Claude Code 事件  →  Hook 脚本(短命)  →  USB 串口  →  XIAO 固件  →  RGB 灯
```

系统三个部分,各自可独立理解与测试。

### 4.1 Claude Code Hooks(配置)
在 Claude Code settings 中注册两个 hook:
- `UserPromptSubmit`(用户提交输入,agent 开始干活)→ 运行脚本发 `1`(亮)
- `Stop`(agent 完成回复,回到空闲)→ 运行脚本发 `0`(灭)

这两个事件精确对应"运行中 vs 空闲"。

### 4.2 Hook 脚本 `mc_light.py`(电脑端)
极简 Python 脚本,接收一个参数(`on` / `off`):
1. 用 `pyserial` 的 `serial.tools.list_ports` 遍历所有串口,按 USB VID `0x2E8A` 自动锁定 XIAO 设备(不硬编码端口名)
2. 打开串口 → 写单个字符(`1` 或 `0`)→ 关闭
3. 串口操作加约 1 秒超时,绝不长时间挂起
4. 找不到设备 / 打开失败 / 写入失败 → 捕获异常,静默退出(返回码 0),不干扰 Claude Code

依赖:`pyserial`(纯 Python,跨平台)。

### 4.3 XIAO 固件 `code.py`(板子端,CircuitPython)
上电即运行的主循环:
1. 通过 `usb_cdc.data` 读**数据串口**(非 REPL 口;CircuitPython 数据串口被打开时不复位程序,故不会闪灯/掉线)
2. 读到 `1` → 灯亮(麦当劳金黄色);读到 `0` → 灯灭
3. 读到未知字符 → 忽略,不崩溃
4. 上电默认状态:灭
5. **看门狗兜底**:超过 10 分钟未再收到"亮"信号则自动熄灭,防止 Claude 异常退出(未触发 `Stop`)时灯常亮

需在 `boot.py` 中启用 `usb_cdc.data`。

### 4.4 通信协议
- 单字符 ASCII
- `1` = 亮,`0` = 灭
- 预留 `2`~`9` 给未来的多态 / 颜色扩展
- 老固件遇到不认识的字符即忽略 —— 向前兼容

## 5. 异常处理与边界情况

灯为辅助设备,绝不能因其故障干扰 Claude Code。原则:hook 脚本永远快速、静默、不报错退出。

| 情况 | 处理方式 |
|---|---|
| 灯没插 / 串口找不到 | 脚本静默退出(exit 0) |
| 串口被占用 / 写入失败 | 捕获异常,静默退出 |
| 串口设备名变化 | 按 USB VID `0x2E8A` 自动查找,不硬编码 |
| 脚本卡住 | 串口操作加约 1 秒超时 |
| 板子上电初始状态 | 默认灭 |
| Claude 异常退出未触发 Stop | 固件 10 分钟看门狗超时熄灭 |
| 收到未知字符 | 固件忽略,不崩溃 |

**看门狗取舍**:超时设 10 分钟兜底,不做周期续命(保持简单)。绝大多数 agent 回合几分钟内结束,10 分钟兜底仅在真正异常时生效。若单次任务超过 10 分钟,灯会误灭 —— 属可接受折衷。

## 6. 跨平台兼容(Windows / Ubuntu)

| 方面 | Windows | Ubuntu |
|---|---|---|
| 串口名 | `COM3`、`COM4`… | `/dev/ttyACM0`… |
| 发现方式 | 统一用 `pyserial` 的 `list_ports` 按 USB VID 匹配,同一段代码两边通用 | 同左 |
| Python 命令 | `python` / `py` | `python3` |
| 依赖安装 | `pip install pyserial` | `pip install pyserial` |

- `mc_light.py` 用 `serial.tools.list_ports` 按 VID `0x2E8A` 自动锁定设备,Windows 与 Ubuntu **同一份脚本、零改动**,并顺带解决两系统端口名都会变的问题
- spec 交付时提供两套 hook 配置示例(Windows 用 `python`,Ubuntu 用 `python3`)
- 固件 `code.py` 与操作系统无关,不受影响

## 7. 测试策略

三部分各自可独立验证。

### 7.1 固件层(XIAO `code.py`)
- 板子插电,用串口终端手动发 `1`/`0`,肉眼确认灯亮/灭
- 发未知字符,确认灯不变、不崩
- 发 `1` 后静置,确认约 10 分钟后自动熄灭(测试时可临时把超时改成 10 秒验证)

### 7.2 Hook 脚本层(`mc_light.py`)
- 命令行手动跑 `python mc_light.py on` / `off`,看灯响应
- 拔掉灯再跑,确认静默退出、返回码 0(`echo $?`)
- 串口名故意写错/被占用,确认不报错、不卡住

### 7.3 集成层(Claude Code hooks)
- 配好 hook 后,在 Claude Code 里发一句话,确认灯亮;答完确认灯灭
- 连续几轮对话,确认灯跟着起伏
- 直接关掉终端,确认灯最终(超时后)熄灭

### 验收标准
插上灯用 Claude Code 时,agent 一干活 M 就亮金色,答完就灭;不插灯时 Claude Code 完全正常。

## 8. 交付物

- `code.py` — XIAO 固件(CircuitPython)
- `boot.py` — 启用 `usb_cdc.data`
- `mc_light.py` — 电脑端 hook 脚本
- hook 配置示例(Windows + Ubuntu)
- 安装/使用说明(含 3D 打印件建议)

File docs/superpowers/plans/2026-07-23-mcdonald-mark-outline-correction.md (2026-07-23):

# McDonald Mark Outline Correction Implementation Plan

> **For agentic workers:** REQUIRED SUB-SKILL: Use superpowers:subagent-driven-development (recommended) or superpowers:executing-plans to implement this plan task-by-task. Steps use checkbox (`- [ ]`) syntax for tracking.

**Goal:** Replace the distorted uniformly buffered mark with a deterministic parametric silhouette that matches `hardware/McDonald.jpeg`.

**Architecture:** Keep `m_polygon(width)` as the only public two-dimensional mark builder. Construct one symmetric polygon from independent outer and inner cubic Bezier segments, then let the existing front-part extrusion and STL export pipeline consume it unchanged.

**Tech Stack:** Python 3, NumPy, Shapely, Trimesh, pytest.

## Global Constraints

- Keep the nominal mark width at `M_WIDTH = 24.0`.
- Keep the front panel at `FRONT_T = 1.2`.
- Keep the red/yellow front parts flush and complementary.
- Do not load `McDonald.jpeg` in production code.
- Do not change back-shell, XIAO, USB, or enclosure dimensions.

---

### Task 1: Correct and Verify the Mark Silhouette

**Files:**
- Modify: `hardware/test_generate_m_shell.py`
- Modify: `hardware/generate_m_shell.py`
- Regenerate: `hardware/mc_light_monitor_front_red.stl`
- Regenerate: `hardware/mc_light_monitor_front_M.stl`
- Regenerate: `hardware/mc_light_monitor_front_assembled.stl`
- Regenerate: `hardware/mc_light_monitor_assembled.stl`

**Interfaces:**
- Consumes: `m_polygon(width: float = M_WIDTH) -> shapely.geometry.Polygon`
- Produces: the same `m_polygon()` interface and the existing `OUTPUTS` meshes.

- [ ] **Step 1: Replace coarse logo tests with reference-derived failing assertions**

Add normalized cross-section assertions:

```python
def test_m_mark_matches_reference_proportions():
    gen = load_generator()
    mark = gen.m_polygon()
    min_x, min_y, max_x, max_y = mark.bounds
    width = max_x - min_x
    height = max_y - min_y

    assert width / height == pytest.approx(1.145, abs=0.025)

    left_outer = vertical_span(mark, min_x + width * 0.04)
    left_leg = vertical_span(mark, min_x + width * 0.125)
    left_crown = vertical_span(mark, min_x + width * 0.25)
    center_foot = vertical_span(mark, min_x + width * 0.50)

    assert left_outer == pytest.approx((min_y, min_y + height * 0.512), abs=height * 0.04)
    assert left_leg == pytest.approx((min_y, min_y + height * 0.830), abs=height * 0.04)
    assert left_crown == pytest.approx(
        (min_y + height * 0.910, min_y + height * 0.994),
        abs=height * 0.035,
    )
    assert center_foot == pytest.approx(
        (min_y + height * 0.071, min_y + height * 0.665),
        abs=height * 0.035,
    )
```

Retain the existing foot-presence assertions and add:

```python
assert mark.is_valid
assert mark.geom_type == "Polygon"
```

- [ ] **Step 2: Run the focused test and verify RED**

Run:

```bash
pytest hardware/test_generate_m_shell.py::test_m_mark_matches_reference_proportions -q
```

Expected: FAIL because the current mark has a width-to-height ratio near `1.04`
and thicker, taller crowns than the reference.

- [ ] **Step 3: Implement one explicit symmetric Bezier outline**

Keep the existing `cubic_points()` evaluator. Replace the line-buffer union with
a polygon contour defined in normalized coordinates:

```python
outer_left = cubic_points((0.0, 0.0), (0.01, 0.64), (0.14, 1.0), (0.275, 1.0), steps)
outer_valley = cubic_points((0.275, 1.0), (0.39, 1.0), (0.47, 0.72), (0.5, 0.665), steps)[1:]
outer = outer_left + outer_valley
outer += [(1.0 - x, y) for x, y in reversed(outer[:-1])]

inner_right = cubic_points((0.865, 0.0), (0.86, 0.55), (0.82, 0.91), (0.75, 0.91), steps)
inner_right += cubic_points((0.75, 0.91), (0.68, 0.91), (0.61, 0.66), (0.56, 0.55), steps)[1:]
inner_right += cubic_points((0.56, 0.55), (0.545, 0.43), (0.545, 0.16), (0.54, 0.071), steps)[1:]
inner_left = [(1.0 - x, y) for x, y in reversed(inner_right)]

normalized = outer + [(1.0, 0.0), (0.865, 0.0)] + inner_right[1:]
normalized += [(0.46, 0.071)] + inner_left[1:] + [(0.0, 0.0)]
points = [(x * width, y * width / 1.145) for x, y in normalized]
poly = Polygon(points)
```

Center the validated polygon from its actual bounds exactly as before. Remove
the no-longer-used `LineString` and `unary_union` imports.

- [ ] **Step 4: Run the focused test and tune only Bezier control points**

Run:

```bash
pytest hardware/test_generate_m_shell.py::test_m_mark_matches_reference_proportions -q
```

Expected: PASS. If a cross-section misses its tolerance, change only the
control points governing that cross-section; do not loosen the tolerance.

- [ ] **Step 5: Run the complete geometry suite**

Run:

```bash
pytest hardware/test_generate_m_shell.py -q
```

Expected: all tests pass.

- [ ] **Step 6: Regenerate STL artifacts**

Run:

```bash
python3 hardware/generate_m_shell.py
```

Expected: five files exported; every line reports `watertight=True`.

- [ ] **Step 7: Perform visual and mesh verification**

Render the normalized corrected silhouette beside the supplied reference and
confirm that the crown thickness, shoulder width, center valley, and three feet
match. Confirm the four changed front/assembly STL files have valid volumes and
the front remains `38 x 38 x 1.2 mm`.

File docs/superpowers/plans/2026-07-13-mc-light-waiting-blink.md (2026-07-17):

# mc-light 等待授权闪烁(第三态)Implementation Plan

> **For agentic workers:** REQUIRED SUB-SKILL: Use superpowers:subagent-driven-development (recommended) or superpowers:executing-plans to implement this plan task-by-task. Steps use checkbox (`- [ ]`) syntax for tracking.

**Goal:** 给 mc-light 增加第三态"等待授权=金色闪烁",授权后恢复常亮,回合结束熄灭。

**Architecture:** 沿用现有三段架构(Claude Code hook 短命脚本 → 单字符 USB 串口 → CircuitPython 固件自持状态)。新增协议字符 `2`=闪烁;固件引入 `OFF/SOLID/BLINK` 模式并在主循环里自持闪烁节奏;主机脚本 `COMMANDS` 增加 `wait`→`2`;hook 配置新增 `Notification`(发 `2`)与 `PostToolUse`(发 `1` 恢复常亮)。

**Tech Stack:** Python 3 + pyserial(主机端,pytest 测试);CircuitPython + neopixel(固件端,硬件手动测试);JSON(hook 配置)。

## Global Constraints

- 协议为单字符 ASCII:`0`=灭,`1`=常亮金,`2`=闪烁;未知字符固件必须忽略、不崩溃(向前兼容)。
- 金色 = `(255, 180, 0)`(固件中常量 `GOLD`)。
- 闪烁节奏:亮 0.5s / 灭 0.5s(周期 1s),硬切换、非渐变。
- 看门狗 = 10 分钟(`WATCHDOG_SECONDS = 600`);SOLID 与 BLINK 都受其管辖。
- hook 脚本必须永远快速、静默、返回码 0,绝不干扰 Claude Code;灯设备缺失/失败一律静默退出。
- 主机脚本发现设备按 USB VID `0x2E8A`,不硬编码端口名。
- 跨平台:Ubuntu 用 `python3`,Windows 用 `python`;`host/mc_light.py` 两平台同一份。
- 测试从 `host/` 目录运行 `python3 -m pytest`(conftest 把 `host/` 加入 sys.path)。

---

### Task 1: 主机脚本新增 `wait` 命令

**Files:**
- Modify: `host/mc_light.py:18`(`COMMANDS` 字典)
- Test: `host/tests/test_mc_light.py`

**Interfaces:**
- Consumes: 现有 `mc_light.COMMANDS`(dict[str, bytes]),`mc_light.main(argv)`。
- Produces: `mc_light.COMMANDS["wait"] == b"2"`;`main(["wait"])` 在找到设备时调用 `send_command(port, b"2")`,无设备/异常时返回 0。

- [ ] **Step 1: Write the failing tests**

在 `host/tests/test_mc_light.py` 末尾追加:

```python
def test_commands_map_wait():
    assert mc_light.COMMANDS["wait"] == b"2"

def test_main_sends_two_for_wait_when_device_found():
    with mock.patch.object(mc_light, "find_light_port", return_value="COM3"), \
         mock.patch.object(mc_light, "send_command") as send:
        assert mc_light.main(["wait"]) == 0
        send.assert_called_once_with("COM3", b"2")
```

- [ ] **Step 2: Run tests to verify they fail**

Run: `cd host && python3 -m pytest tests/test_mc_light.py::test_commands_map_wait tests/test_mc_light.py::test_main_sends_two_for_wait_when_device_found -v`
Expected: FAIL(`KeyError: 'wait'`)

- [ ] **Step 3: Add `wait` to COMMANDS**

把 `host/mc_light.py` 的 `COMMANDS` 改为:

```python
COMMANDS = {"on": b"1", "off": b"0", "wait": b"2"}
```

- [ ] **Step 4: Run full host test suite to verify pass**

Run: `cd host && python3 -m pytest -v`
Expected: PASS(含原有全部用例 + 两条新用例)

- [ ] **Step 5: Commit**

```bash
git add host/mc_light.py host/tests/test_mc_light.py
git commit -m "feat(host): add wait command sending '2' for auth-waiting state"
```

---

### Task 2: 固件新增 BLINK 模式

**Files:**
- Modify: `firmware/code.py`(整段主循环与状态变量)

**Interfaces:**
- Consumes: `GOLD`、`OFF`、`WATCHDOG_SECONDS`、`pixel`、`serial`(现有)。
- Produces: 无被其它任务依赖的接口;这是固件端行为改动。行为契约:收 `1`→常亮金,`2`→闪烁(亮 0.5s/灭 0.5s),`0`→灭;SOLID/BLINK 均受 10 分钟看门狗;未知字符忽略。

> **说明:** 固件运行在 CircuitPython 硬件上(`import board/neopixel/usb_cdc`),无法在开发机跑单元测试。本任务用**硬件手动测试**验证(见 Step 3)。改动集中在状态机与主循环。

- [ ] **Step 1: 用模式状态机重写主循环**

把 `firmware/code.py` 第 26 行起(`last_on = None` 到文件末尾)替换为:

```python
# 当前模式:"off" / "solid" / "blink"
mode = "off"
mode_since = time.monotonic()   # 进入当前(非灭)模式的时刻,用于看门狗
blink_on = False                # blink 模式下当前灯是否亮着
last_toggle = time.monotonic()  # 上次翻转时刻
BLINK_INTERVAL = 0.5            # 闪烁半周期:亮 0.5s / 灭 0.5s

def set_mode(new_mode):
    global mode, mode_since, blink_on, last_toggle
    mode = new_mode
    now = time.monotonic()
    if new_mode == "off":
        pixel[0] = OFF
    elif new_mode == "solid":
        pixel[0] = GOLD
        mode_since = now
    elif new_mode == "blink":
        blink_on = True
        pixel[0] = GOLD
        last_toggle = now
        mode_since = now

while True:
    if serial is not None and serial.in_waiting > 0:
        data = serial.read(serial.in_waiting)
        for b in data:
            ch = chr(b)
            if ch == "1":
                set_mode("solid")
            elif ch == "2":
                set_mode("blink")
            elif ch == "0":
                set_mode("off")
            # 其它字符(含预留 3-9)忽略

    now = time.monotonic()

    # 闪烁:按半周期翻转
    if mode == "blink" and (now - last_toggle) >= BLINK_INTERVAL:
        blink_on = not blink_on
        pixel[0] = GOLD if blink_on else OFF
        last_toggle = now

    # 看门狗:solid / blink 超时自动灭
    if mode in ("solid", "blink") and (now - mode_since) > WATCHDOG_SECONDS:
        set_mode("off")

    time.sleep(0.05)
```

同时删除原有 `last_on = None` 及其下的旧 `while True` 循环(被上面整体替换)。文件顶部的 imports、`GOLD`/`OFF`/`WATCHDOG_SECONDS` 常量、NeoPixel 电源与初始化、`serial = usb_cdc.data` 部分保持不变。

- [ ] **Step 2: 静态自检(语法与结构)**

Run: `python3 -c "import ast; ast.parse(open('firmware/code.py').read()); print('syntax OK')"`
Expected: 输出 `syntax OK`(仅验证语法;CircuitPython 专有模块无法在开发机导入)

- [ ] **Step 3: 硬件手动测试(把 code.py 拷到 CIRCUITPY 后)**

用串口终端向数据口逐一发送并肉眼确认:
- 发 `1` → 常亮金
- 发 `2` → 金色闪烁(亮约 0.5s、灭约 0.5s)
- 闪烁中发 `1` → 立即转常亮
- 闪烁中发 `0` → 立即灭
- 发未知字符(如 `x`)→ 灯不变、不崩
- (可选)把 `WATCHDOG_SECONDS` 临时改成 `10`,发 `2` 后静置,确认约 10 秒后自动灭;验证完改回 `600`

- [ ] **Step 4: Commit**

```bash
git add firmware/code.py
git commit -m "feat(firmware): add blink mode for auth-waiting (protocol '2')"
```

---

### Task 3: Hook 配置新增 Notification 与 PostToolUse

**Files:**
- Modify: `hooks/settings.ubuntu.json`
- Modify: `hooks/settings.windows.json`

**Interfaces:**
- Consumes: Task 1 的 `mc_light.py wait`(发 `2`)与现有 `on`(发 `1`)。
- Produces: 两份配置示例,各含 `UserPromptSubmit`/`Notification`/`PostToolUse`/`Stop` 四个 hook。

> **说明:** JSON 配置示例,无自动化测试;验证方式为 JSON 合法性 + 人工核对事件映射。

- [ ] **Step 1: 更新 Ubuntu 配置**

把 `hooks/settings.ubuntu.json` 整体替换为:

```json
{
  "hooks": {
    "UserPromptSubmit": [
      {
        "hooks": [
          { "type": "command", "command": "python3 /ABSOLUTE/PATH/mc-light/host/mc_light.py on" }
        ]
      }
    ],
    "Notification": [
      {
        "hooks": [
          { "type": "command", "command": "python3 /ABSOLUTE/PATH/mc-light/host/mc_light.py wait" }
        ]
      }
    ],
    "PostToolUse": [
      {
        "hooks": [
          { "type": "command", "command": "python3 /ABSOLUTE/PATH/mc-light/host/mc_light.py on" }
        ]
      }
    ],
    "Stop": [
      {
        "hooks": [
          { "type": "command", "command": "python3 /ABSOLUTE/PATH/mc-light/host/mc_light.py off" }
        ]
      }
    ]
  }
}
```

- [ ] **Step 2: 更新 Windows 配置**

把 `hooks/settings.windows.json` 整体替换为:

```json
{
  "hooks": {
    "UserPromptSubmit": [
      {
        "hooks": [
          { "type": "command", "command": "python C:\\ABSOLUTE\\PATH\\mc-light\\host\\mc_light.py on" }
        ]
      }
    ],
    "Notification": [
      {
        "hooks": [
          { "type": "command", "command": "python C:\\ABSOLUTE\\PATH\\mc-light\\host\\mc_light.py wait" }
        ]
      }
    ],
    "PostToolUse": [
      {
        "hooks": [
          { "type": "command", "command": "python C:\\ABSOLUTE\\PATH\\mc-light\\host\\mc_light.py on" }
        ]
      }
    ],
    "Stop": [
      {
        "hooks": [
          { "type": "command", "command": "python C:\\ABSOLUTE\\PATH\\mc-light\\host\\mc_light.py off" }
        ]
      }
    ]
  }
}
```

- [ ] **Step 3: 验证两份 JSON 合法**

Run: `python3 -c "import json; json.load(open('hooks/settings.ubuntu.json')); json.load(open('hooks/settings.windows.json')); print('json OK')"`
Expected: 输出 `json OK`

- [ ] **Step 4: Commit**

```bash
git add hooks/settings.ubuntu.json hooks/settings.windows.json
git commit -m "feat(hooks): add Notification (blink) and PostToolUse (solid) hooks"
```

---

### Task 4: 更新 README

**Files:**
- Modify: `README.md`(工作原理、事件映射、验收)

**Interfaces:**
- Consumes: 上述三态协议与四个 hook 事件。
- Produces: 文档,无测试。

- [ ] **Step 1: 更新"工作原理"事件映射段**

把 `README.md` 中"工作原理"下的事件列表(现为 `UserPromptSubmit → 1` / `Stop → 0` 两条)替换为:

```markdown
- `UserPromptSubmit` → 发 `1`(常亮金,干活中)
- `Notification`(需要授权)→ 发 `2`(金色闪烁,等待授权)
- `PostToolUse`(工具执行完,含授权后)→ 发 `1`(恢复常亮)
- `Stop` → 发 `0`(灭,空闲)
- 脚本按 USB VID `0x2E8A` 自动找设备,不硬编码端口名。
- 找不到灯或出错时脚本静默退出,绝不影响 Claude Code。
- 固件 10 分钟看门狗:常亮或闪烁超时未更新则自动熄灭。
```

- [ ] **Step 2: 更新顶部一句话描述**

把 `README.md` 第 3 行改为:

```markdown
感知 Claude Code agent 状态的麦当劳金拱门 "M" 指示灯。agent 干活时 M 常亮金色,等待授权时闪烁,空闲时熄灭。USB 连接,跨平台(Windows / Ubuntu)。
```

- [ ] **Step 3: 更新"验收"段**

把 `README.md` 末尾"验收"段落正文替换为:

```markdown
插上灯用 Claude Code:发一句话 → M 常亮金;触发需要授权的操作 → M 闪烁;点允许 → M 恢复常亮;答完 → M 灭。不插灯时 Claude Code 完全正常。
```

- [ ] **Step 4: Commit**

```bash
git add README.md
git commit -m "docs: document three-state behavior and new hooks"
```

---

## Self-Review

**1. Spec coverage:**
- 协议 `2`=闪烁 → Task 1(主机)+ Task 2(固件)✓
- 事件映射 `Notification`/`PostToolUse` → Task 3 ✓
- 固件 BLINK 模式 + 看门狗纳入 → Task 2 ✓
- 主机 `COMMANDS` 加 `wait` → Task 1 ✓
- README 更新 → Task 4 ✓
- 硬件/3D 打印件/设备发现逻辑不动 → 计划中未触碰,符合非目标 ✓

**2. Placeholder scan:** 无 TBD/TODO;每个代码步骤含完整代码;JSON/固件全文给出。✓

**3. Type consistency:** `COMMANDS["wait"] == b"2"` 在 Task 1 定义、Task 3 引用一致;固件模式字符串 `"off"/"solid"/"blink"` 与 `set_mode` 全程一致;`GOLD/OFF/WATCHDOG_SECONDS/BLINK_INTERVAL` 命名一致。✓

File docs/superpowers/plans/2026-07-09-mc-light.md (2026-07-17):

# mc-light Implementation Plan

> **For agentic workers:** REQUIRED SUB-SKILL: Use superpowers:subagent-driven-development (recommended) or superpowers:executing-plans to implement this plan task-by-task. Steps use checkbox (`- [ ]`) syntax for tracking.

**Goal:** Build a USB-connected "麦当劳金拱门 M" indicator light that turns gold while a Claude Code agent is working and off when idle.

**Architecture:** Claude Code hooks fire short-lived Python scripts that write a single ASCII char over USB serial to a Seeed XIAO RP2040. CircuitPython firmware on the board reads the char and sets its onboard NeoPixel. Host script is unit-testable (mocked serial); firmware is hardware-tested manually.

**Tech Stack:** Python 3 + pyserial (host), CircuitPython + neopixel + usb_cdc (firmware), pytest (host tests).

## Global Constraints

- Host script must NEVER disrupt Claude Code: on any error (no device, port busy, write fail) it exits 0 silently.
- Never hardcode the serial port name — discover by USB VID `0x2E8A` (RP2040).
- Serial operations use a ~1 second timeout; never hang.
- Protocol: single ASCII char. `1` = on, `0` = off. `2`–`9` reserved; unknown chars ignored by firmware (forward-compatible).
- Firmware power-on default: OFF.
- Firmware watchdog: auto-off after 600 seconds (10 min) without a new "on".
- Light color when on: McDonald's gold `(255, 180, 0)`.
- Cross-platform: one host script for Windows and Ubuntu (VID-based discovery); only the `python` vs `python3` invocation differs, handled in hook config.

---

### Task 1: Host — discover the light's serial port by USB VID

**Files:**
- Create: `host/mc_light.py`
- Create: `host/requirements.txt`
- Test: `host/tests/test_mc_light.py`

**Interfaces:**
- Consumes: nothing (first task).
- Produces: `find_light_port(vid: int = 0x2E8A) -> str | None` — returns the port device name (e.g. `"COM3"` / `"/dev/ttyACM0"`) of the first serial port whose USB VID matches, else `None`. Module constant `XIAO_VID = 0x2E8A`.

- [ ] **Step 1: Create requirements file**

Create `host/requirements.txt`:

```
pyserial>=3.5
pytest>=7.0
```

Install: `pip install -r host/requirements.txt`

- [ ] **Step 2: Write the failing test**

Create `host/tests/test_mc_light.py`:

```python
from types import SimpleNamespace
from unittest import mock

import mc_light

def _port(vid, device):
    return SimpleNamespace(vid=vid, device=device)

def test_find_light_port_returns_matching_device():
    ports = [_port(0x1234, "COM1"), _port(0x2E8A, "COM3")]
    with mock.patch.object(mc_light.list_ports, "comports", return_value=ports):
        assert mc_light.find_light_port() == "COM3"

def test_find_light_port_returns_none_when_no_match():
    ports = [_port(0x1234, "COM1"), _port(None, "COM2")]
    with mock.patch.object(mc_light.list_ports, "comports", return_value=ports):
        assert mc_light.find_light_port() is None
```

- [ ] **Step 3: Run test to verify it fails**

Run: `cd host && python -m pytest tests/test_mc_light.py -v`
Expected: FAIL — `ModuleNotFoundError: No module named 'mc_light'` (or `AttributeError` on `find_light_port`).

- [ ] **Step 4: Write minimal implementation**

Create `host/mc_light.py`:

```python
"""mc-light host hook script: send on/off over USB serial to the XIAO RP2040."""
import sys

import serial
from serial.tools import list_ports

XIAO_VID = 0x2E8A

def find_light_port(vid=XIAO_VID):
    """Return the device name of the first serial port matching `vid`, else None."""
    for port in list_ports.comports():
        if port.vid == vid:
            return port.device
    return None
```

- [ ] **Step 5: Run test to verify it passes**

Run: `cd host && python -m pytest tests/test_mc_light.py -v`
Expected: PASS (2 passed).

- [ ] **Step 6: Commit**

```bash
git add host/mc_light.py host/requirements.txt host/tests/test_mc_light.py
git commit -m "feat(host): discover XIAO light port by USB VID"
```

---

### Task 2: Host — send a command byte over serial with timeout

**Files:**
- Modify: `host/mc_light.py`
- Test: `host/tests/test_mc_light.py`

**Interfaces:**
- Consumes: `find_light_port` (Task 1).
- Produces: `send_command(port: str, byte: bytes, timeout: float = 1.0) -> None` — opens the serial port with read+write timeouts, writes `byte`, closes. Raises on failure (caller decides how to handle). Module constant `COMMANDS = {"on": b"1", "off": b"0"}`.

- [ ] **Step 1: Write the failing test**

Append to `host/tests/test_mc_light.py`:

```python
def test_send_command_opens_with_timeouts_and_writes():
    fake_ser = mock.MagicMock()
    fake_ser.__enter__.return_value = fake_ser
    with mock.patch.object(mc_light.serial, "Serial", return_value=fake_ser) as ctor:
        mc_light.send_command("COM3", b"1", timeout=1.0)
    ctor.assert_called_once_with("COM3", timeout=1.0, write_timeout=1.0)
    fake_ser.write.assert_called_once_with(b"1")

def test_commands_map_on_off():
    assert mc_light.COMMANDS["on"] == b"1"
    assert mc_light.COMMANDS["off"] == b"0"
```

- [ ] **Step 2: Run test to verify it fails**

Run: `cd host && python -m pytest tests/test_mc_light.py -v`
Expected: FAIL — `AttributeError: module 'mc_light' has no attribute 'send_command'`.

- [ ] **Step 3: Write minimal implementation**

Add to `host/mc_light.py` (after `find_light_port`):

```python
COMMANDS = {"on": b"1", "off": b"0"}

def send_command(port, byte, timeout=1.0):
    """Open `port`, write `byte`, close. Raises on failure."""
    with serial.Serial(port, timeout=timeout, write_timeout=timeout) as ser:
        ser.write(byte)
```

- [ ] **Step 4: Run test to verify it passes**

Run: `cd host && python -m pytest tests/test_mc_light.py -v`
Expected: PASS (4 passed).

- [ ] **Step 5: Commit**

```bash
git add host/mc_light.py host/tests/test_mc_light.py
git commit -m "feat(host): send command byte over serial with timeout"
```

---

### Task 3: Host — CLI entry point that never disrupts Claude Code

**Files:**
- Modify: `host/mc_light.py`
- Test: `host/tests/test_mc_light.py`

**Interfaces:**
- Consumes: `find_light_port`, `send_command`, `COMMANDS`.
- Produces: `main(argv: list[str] | None = None) -> int` — parses `argv[0]` (`"on"`/`"off"`); ALWAYS returns 0. Unknown arg → return 0 (no serial). No device → return 0 (no send). `send_command` raises → swallow, return 0. `__main__` calls `sys.exit(main())`.

- [ ] **Step 1: Write the failing test**

Append to `host/tests/test_mc_light.py`:

```python
def test_main_unknown_arg_returns_0_and_skips_serial():
    with mock.patch.object(mc_light, "find_light_port") as find:
        assert mc_light.main(["bogus"]) == 0
        find.assert_not_called()

def test_main_no_arg_returns_0():
    assert mc_light.main([]) == 0

def test_main_no_device_returns_0_and_skips_send():
    with mock.patch.object(mc_light, "find_light_port", return_value=None), \
         mock.patch.object(mc_light, "send_command") as send:
        assert mc_light.main(["on"]) == 0
        send.assert_not_called()

def test_main_sends_correct_byte_when_device_found():
    with mock.patch.object(mc_light, "find_light_port", return_value="COM3"), \
         mock.patch.object(mc_light, "send_command") as send:
        assert mc_light.main(["off"]) == 0
        send.assert_called_once_with("COM3", b"0")

def test_main_returns_0_when_send_raises():
    with mock.patch.object(mc_light, "find_light_port", return_value="COM3"), \
         mock.patch.object(mc_light, "send_command", side_effect=OSError("busy")):
        assert mc_light.main(["on"]) == 0
```

- [ ] **Step 2: Run test to verify it fails**

Run: `cd host && python -m pytest tests/test_mc_light.py -v`
Expected: FAIL — `AttributeError: module 'mc_light' has no attribute 'main'`.

- [ ] **Step 3: Write minimal implementation**

Add to end of `host/mc_light.py`:

```python
def main(argv=None):
    argv = argv if argv is not None else sys.argv[1:]
    if not argv or argv[0] not in COMMANDS:
        return 0
    byte = COMMANDS[argv[0]]
    port = find_light_port()
    if port is None:
        return 0
    try:
        send_command(port, byte)
    except Exception:
        pass
    return 0

if __name__ == "__main__":
    sys.exit(main())
```

- [ ] **Step 4: Run test to verify it passes**

Run: `cd host && python -m pytest tests/test_mc_light.py -v`
Expected: PASS (9 passed).

- [ ] **Step 5: Manual smoke test (no hardware needed)**

Run: `cd host && python mc_light.py on; echo "exit=$?"`
Expected: prints `exit=0` even with no light plugged in (silent, no traceback).

- [ ] **Step 6: Commit**

```bash
git add host/mc_light.py host/tests/test_mc_light.py
git commit -m "feat(host): CLI entry point that always exits 0"
```

---

### Task 4: Firmware — boot.py + code.py for the XIAO RP2040

**Files:**
- Create: `firmware/boot.py`
- Create: `firmware/code.py`

**Interfaces:**
- Consumes: the single-char protocol from Global Constraints.
- Produces: firmware that reads `usb_cdc.data` and drives the onboard NeoPixel. No unit tests (CircuitPython hardware modules); manual hardware tests below (spec §7.1).

> **Note:** These files are copied onto the board's `CIRCUITPY` USB drive; they run on the board, not on the host. Requires CircuitPython installed on the XIAO RP2040 and the `neopixel` library present in `CIRCUITPY/lib/`.

- [ ] **Step 1: Create boot.py (enable the data serial port)**

Create `firmware/boot.py`:

```python
# 启用第二路 USB 串口(数据口),打开它不会复位正在运行的程序
import usb_cdc

usb_cdc.enable(console=True, data=True)
```

- [ ] **Step 2: Create code.py (main loop)**

Create `firmware/code.py`:

```python
# mc-light 固件:读 USB 数据串口的单字符,驱动板载 NeoPixel
import time

import board
import digitalio
import neopixel
import usb_cdc

GOLD = (255, 180, 0)          # 麦当劳金黄色
OFF = (0, 0, 0)
WATCHDOG_SECONDS = 600        # 10 分钟兜底熄灭

# XIAO RP2040 板载 NeoPixel 需要先给 NEOPIXEL_POWER 供电
power = digitalio.DigitalInOut(board.NEOPIXEL_POWER)
power.direction = digitalio.Direction.OUTPUT
power.value = True

pixel = neopixel.NeoPixel(board.NEOPIXEL, 1)
pixel.brightness = 0.5
pixel[0] = OFF                # 上电默认:灭

serial = usb_cdc.data         # 数据口(非 REPL 控制台口)
if serial is not None:
    serial.timeout = 0        # 非阻塞读

last_on = None                # 上次点亮时刻;None 表示当前熄灭

while True:
    if serial is not None and serial.in_waiting > 0:
        data = serial.read(serial.in_waiting)
        for b in data:
            ch = chr(b)
            if ch == "1":
                pixel[0] = GOLD
                last_on = time.monotonic()
            elif ch == "0":
                pixel[0] = OFF
                last_on = None
            # 其它字符(含预留 2-9)忽略
    # 看门狗:亮着且超时则自动熄灭
    if last_on is not None and (time.monotonic() - last_on) > WATCHDOG_SECONDS:
        pixel[0] = OFF
        last_on = None
    time.sleep(0.05)
```

- [ ] **Step 3: Deploy to the board**

- Flash CircuitPython onto the XIAO RP2040 (drag the UF2 while holding BOOT).
- Copy `neopixel.mpy` (+ its deps) into `CIRCUITPY/lib/` from the CircuitPython library bundle.
- Copy `firmware/boot.py` and `firmware/code.py` to the `CIRCUITPY` drive root.
- Eject and replug so `boot.py` takes effect (data serial port appears).

- [ ] **Step 4: Manual hardware test — on/off (spec §7.1)**

Open a serial terminal on the **data** port (not the REPL/console port). Send `1` → M lights gold. Send `0` → M goes off. Send `x` → no change, no crash.

- [ ] **Step 5: Manual hardware test — watchdog**

Temporarily set `WATCHDOG_SECONDS = 10` in `code.py`, save, let the board reload. Send `1`, wait ~10s without sending anything → light auto-turns off. Restore `WATCHDOG_SECONDS = 600` afterward.

- [ ] **Step 6: Commit**

```bash
git add firmware/boot.py firmware/code.py
git commit -m "feat(firmware): NeoPixel control loop with watchdog for XIAO RP2040"
```

---

### Task 5: Claude Code hook config + README

**Files:**
- Create: `hooks/settings.ubuntu.json`
- Create: `hooks/settings.windows.json`
- Create: `README.md`

**Interfaces:**
- Consumes: `host/mc_light.py` CLI (`on`/`off`), firmware behavior.
- Produces: copy-paste hook config for both OSes and end-to-end setup docs.

- [ ] **Step 1: Create Ubuntu hook config example**

Create `hooks/settings.ubuntu.json` (merge into `~/.claude/settings.json`; adjust the absolute path):

```json
{
  "hooks": {
    "UserPromptSubmit": [
      {
        "hooks": [
          { "type": "command", "command": "python3 /ABSOLUTE/PATH/mc-light/host/mc_light.py on" }
        ]
      }
    ],
    "Stop": [
      {
        "hooks": [
          { "type": "command", "command": "python3 /ABSOLUTE/PATH/mc-light/host/mc_light.py off" }
        ]
      }
    ]
  }
}
```

- [ ] **Step 2: Create Windows hook config example**

Create `hooks/settings.windows.json`:

```json
{
  "hooks": {
    "UserPromptSubmit": [
      {
        "hooks": [
          { "type": "command", "command": "python C:\\ABSOLUTE\\PATH\\mc-light\\host\\mc_light.py on" }
        ]
      }
    ],
    "Stop": [
      {
        "hooks": [
          { "type": "command", "command": "python C:\\ABSOLUTE\\PATH\\mc-light\\host\\mc_light.py off" }
        ]
      }
    ]
  }
}
```

- [ ] **Step 3: Create README**

Create `README.md`:

````markdown
# mc-light

感知 Claude Code agent 状态的麦当劳金拱门 "M" 指示灯。agent 干活时 M 亮金色,空闲时熄灭。USB 连接,跨平台(Windows / Ubuntu)。

## 硬件

- Seeed XIAO RP2040 ×1(板载 NeoPixel RGB 灯)
- USB-C 数据线 ×1(必须是数据线,非纯充电线)
- 3D 打印:半透明金拱门 M 外壳(约 6cm)+ 底座,PLA 半透明/白色。M 罩在板载灯珠上方,靠打印件壁厚做光线漫射。

## 安装

### 1. 固件(板子端)
1. 给 XIAO RP2040 刷 CircuitPython。
2. 把 `neopixel.mpy` 放进 `CIRCUITPY/lib/`。
3. 复制 `firmware/boot.py`、`firmware/code.py` 到 `CIRCUITPY` 根目录,重新插拔。

### 2. 主机脚本(电脑端)
```
pip install -r host/requirements.txt
```
自测:`python host/mc_light.py on`(不插灯也应静默退出、返回 0)。

### 3. Claude Code hooks
把 `hooks/settings.ubuntu.json`(Ubuntu)或 `hooks/settings.windows.json`(Windows)的内容合并进 `~/.claude/settings.json`,并把命令里的路径改成你的绝对路径。Windows 用 `python`,Ubuntu 用 `python3`。

## 工作原理

```
Claude Code 事件 → hook 脚本 → USB 串口(单字符 1/0)→ XIAO 固件 → RGB 灯
```

- `UserPromptSubmit` → 发 `1`(亮金色)
- `Stop` → 发 `0`(灭)
- 脚本按 USB VID `0x2E8A` 自动找设备,不硬编码端口名。
- 找不到灯或出错时脚本静默退出,绝不影响 Claude Code。
- 固件 10 分钟看门狗:若 Claude 异常退出未发 `0`,灯会自动熄灭。

## 验收

插上灯用 Claude Code:发一句话 → M 亮金色;答完 → M 灭。不插灯时 Claude Code 完全正常。
````

- [ ] **Step 4: Commit**

```bash
git add hooks/settings.ubuntu.json hooks/settings.windows.json README.md
git commit -m "docs: add hook config examples and setup README"
```

---

## Self-Review

**Spec coverage:**
- §3 硬件/BOM → README Task 5 ✓
- §4.1 hooks (UserPromptSubmit/Stop) → Task 5 configs ✓
- §4.2 host script (VID discovery, write char, timeout, silent exit) → Tasks 1–3 ✓
- §4.3 firmware (usb_cdc.data, on/off, ignore unknown, default off, 10-min watchdog) → Task 4 ✓
- §4.4 protocol (1/0, reserved 2–9 ignored) → Task 2 COMMANDS + Task 4 loop ✓
- §5 error handling (all rows) → Task 3 main + Task 4 firmware ✓
- §6 cross-platform (one script, python vs python3) → VID discovery Task 1 + Task 5 dual configs ✓
- §7 testing → unit tests Tasks 1–3, manual hardware tests Task 4 steps 4–5, integration in README acceptance ✓
- §8 deliverables (code.py, boot.py, mc_light.py, hook configs, README) → all created ✓

**Placeholder scan:** No TBD/TODO; all code shown in full. Absolute paths in configs are intentional user-substituted placeholders, labeled as such. ✓

**Type consistency:** `find_light_port() -> str|None`, `send_command(port, byte, timeout)`, `COMMANDS` dict, `main(argv) -> int` used consistently across Tasks 1–3 and tests. Firmware chars `"1"/"0"` match host bytes `b"1"/b"0"`. ✓

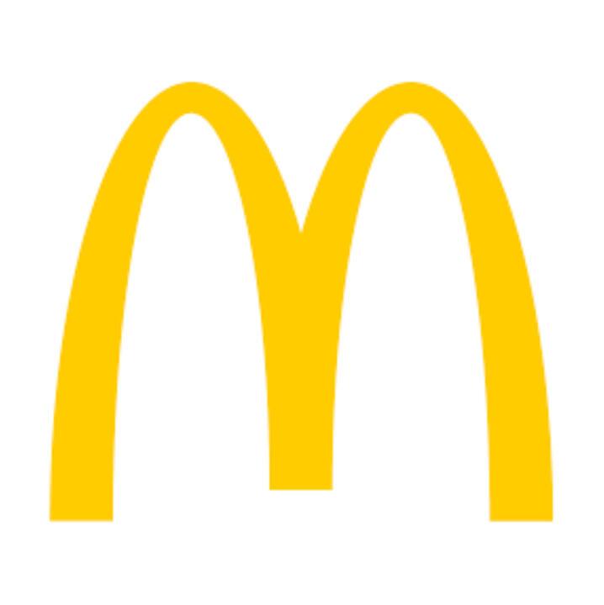
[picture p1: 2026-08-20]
hardware/McDonald.jpeg

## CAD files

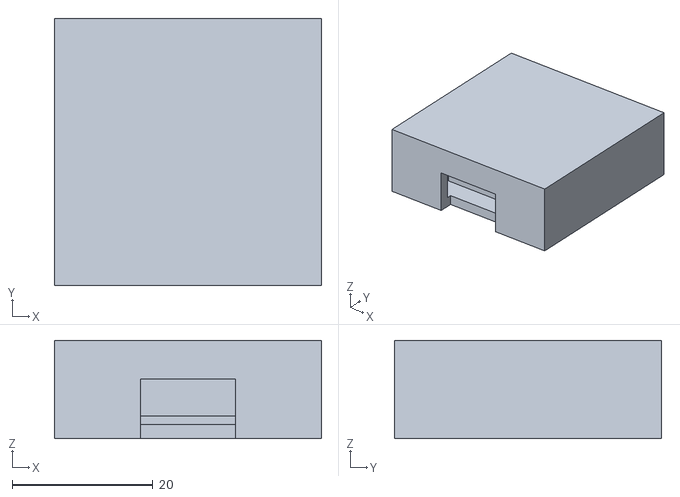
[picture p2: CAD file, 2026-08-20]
hardware/mc_light_monitor_assembled.stl
38.0 x 38.0 x 14.0

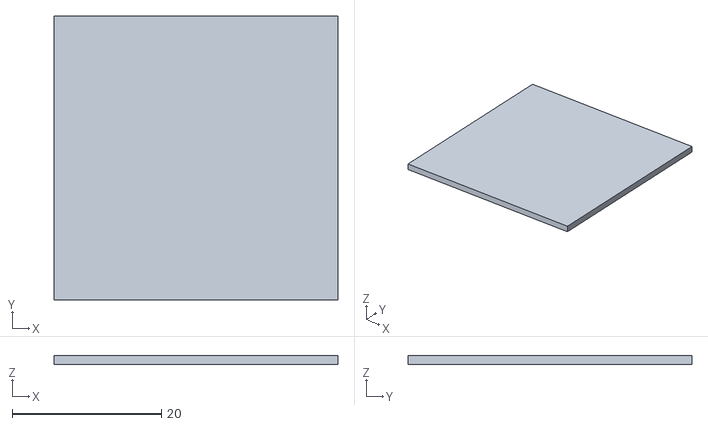
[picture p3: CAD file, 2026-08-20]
hardware/mc_light_monitor_front_assembled.stl
38.0 x 38.0 x 1.20

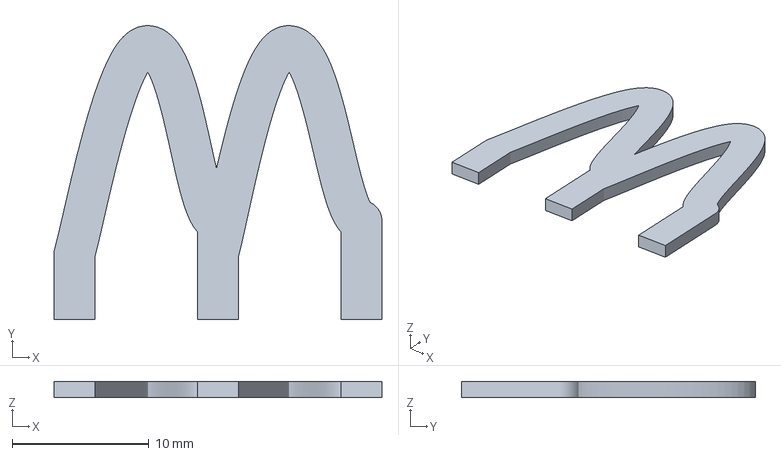
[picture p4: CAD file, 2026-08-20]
hardware/mc_light_monitor_front_M.3mf
24.0 x 21.5 x 1.20 mm

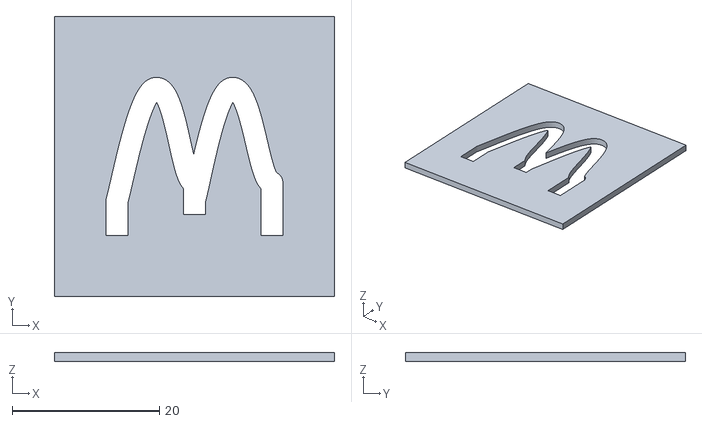
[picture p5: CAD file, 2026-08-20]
hardware/mc_light_monitor_front_red.stl
38.0 x 38.0 x 1.20

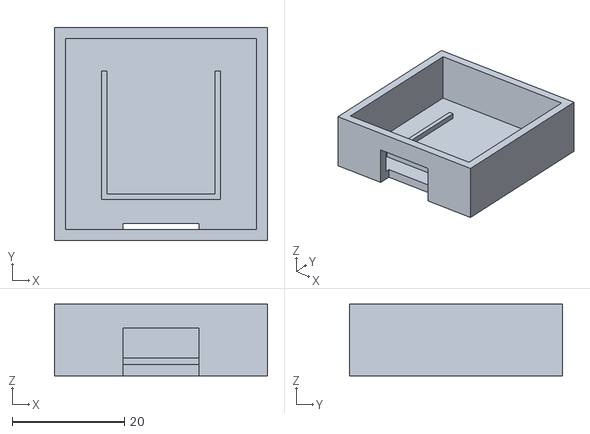
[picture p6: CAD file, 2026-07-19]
hardware/mc_light_monitor_back.stl
38.0 x 38.0 x 12.8

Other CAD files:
hardware/mc_light_monitor_front_M.gcode.3mf
hardware/mc_light_monitor_front_M.stl

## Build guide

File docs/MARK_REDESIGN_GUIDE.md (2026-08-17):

# 麦当劳 M 标志重新设计教程

> 给小白的、从零开始的、用 FreeCAD 或 Blender 重新设计 mc-light 显示器侧贴 M 灯标志的指引

## 0. 你为什么会看到这份文档

`mc-light/hardware/mc_light_monitor_front_M.stl` 是**程序化生成**的 M 标志(用 Python + shapely + trimesh 算出贝塞尔曲线)。当前默认参数(M_WIDTH=24, LEG_H=12, ARCH_R=6)产生的 M 比例是 **24mm 宽 × 21.5mm 高(1.12:1)**,太瘦、太尖锐、腿短。

**真实麦当劳金拱门 M 的宽高比 ≈ 1.3:1**(参考官网 logo 规范和 Wikipedia),即 24mm 宽应当对应 18-19mm 高,而且:
- 拱的弧度更平缓(不是尖锐抛物线)
- 腿更短(脚不落地或浅落地)
- 笔画的"中央 V 形"角度更大、更圆润

这份教程**不改** `generate_m_shell.py` 也不改 STL,**教你从零画一个**几何上更接近真标的 M 标志,然后**替换** `mc_light_monitor_front_M.stl`。

## 1. 准备

### 1.1 工具(任选一个,二选一)

| 工具 | 适合谁 | 安装 | 体量 |
|---|---|---|---|
| **FreeCAD 1.0** | 想精确参数化、要走 Part Design 工作流、能用 Python 脚本 | `sudo apt install freecad` 或 `conda install -c conda-forge freecad` | ~500MB |
| **Blender 4.x** | 习惯 Blender、想直观捏模型、要先预览切片 | `sudo apt install blender` 或 https://blender.org/download | ~300MB(已装在 `/usr/bin/blender`) |

**推荐:FreeCAD 主画 + Blender 验证**。

### 1.2 关键参考

1. **McDonald’s 官方品牌资源**:
   - 搜索 "McDonald's Golden Arches brand guidelines" 看真标比例
   - 维基百科:https://en.wikipedia.org/wiki/McDonald%27s_(wordmark) 的 "Logo" 章节
2. **几何规范(常用参考)**:
   - 整个 M 宽 24mm,高 18mm(宽高比 1.33:1)
   - 腿宽(底端笔画粗)≈ 3.5mm
   - 中央 V 形底端点(最深处)y ≈ -2mm(在 M 几何中心之下)
   - 拱顶最高点 y ≈ 9mm
3. **最终尺寸**(你最终要导出的 STL):
   - 宽 24mm × 高 18mm × 厚 1.2mm(跟灯盒 `FRONT_T=1.2mm` 匹配)

## 2. 方法 A:FreeCAD(推荐)

### 2.1 启动 + 切换工作台

1. 终端:`freecad` (或 `freecad &` 后台)
2. **菜单 → 工作台 → Part Design**(图标是蓝色立方体带斜线)
3. **视图 → 视图 → Standard / Orthographic**(正视,正交投影)
4. 鼠标:中键拖动旋转,Shift+中键平移,滚轮缩放

### 2.2 画 M 草图(Sketcher)

**步骤 1:创建 Body**
- 工具栏 → `Create body`(一个空 Body 出现在树里)
- 选中 Body → `Create sketch` → 选 **XY 平面**
- 进入 Sketcher 工作台

**步骤 2:画 M 的 6 个关键点**

按真实麦当劳比例,在草图里画以下 6 个点(原点 0,0 = M 几何中心):

```
       P3 ( -3.6,  9.0 )              P4 ( 3.6, 9.0)        ← 拱顶
        ╱ ── ── ── ── ── ── ╲      ╱
       ╱                       ╲  ╱
      ╱                          ╲╱
P1 (-12, -9)  P5 (-3.6, -2)  P2 (0, -2)  P6 (3.6, -2)  P7 (12, -9)   ← 脚
└── 左腿 ──┘  └── 左 V 边──┘ └ 中┘ └── 右 V 边──┘  └── 右腿 ──┘
```

**操作**:
- 工具栏选 `Create point`(点工具)
- 在草图区点击放 7 个点(P1..P7,顺序:左下脚→左拱起→中 V 左→中 V 右→右拱起→右下脚,**M 是连续一笔画**)
- 点位置输坐标(选点 → 左下角属性面板改 X/Y,或 F2 编辑):
  - P1: (-12, -9)
  - P3: (-3.6, 9.0) ← 左拱顶
  - P5: (-3.6, -2) ← 左 V 底
  - P2: (0, -2) ← V 最低点(中央)
  - P6: (3.6, -2) ← 右 V 底
  - P4: (3.6, 9.0) ← 右拱顶
  - P7: (12, -9)

> 7 个点 P1..P7 是 M 的关键"骨架"点。M 实际是 1 条闭合曲线 + 2 个矩形(腿填充),但 FreeCAD 草图先从点开始,再用 B-Spline 连。

**步骤 3:用 B-Spline 把点连成 M 形状**

- 工具栏 `Create B-spline`(贝塞尔曲线工具)
- 从 P1 开始,依次点击 P3, P2, P4, P7(让 spline 穿过这 5 个点)
- 闭合:spline 末尾再点一次 P1
- 这是 M 的**中线**(一根线)

> ⚠️ 如果 P1→P3→P2→P4→P7 这条线在 P2 拐弯太尖锐,选中 spline → 控制点模式 → 拖 P2 的两个控制柄让 V 形更圆润。

**步骤 4:腿的宽度(关键!)**

麦当劳 M 的腿是**有厚度的**,不是你刚画的中线。两种做法:

**做法 1:用 Offset(推荐)**
- 工具栏 `Create offset`
- 选刚才的 spline
- 偏移距离 = `1.75` mm(半个腿宽)
- 方向:向外(远离中线)
- 现在有了 2 条平行 spline(中线 + 外缘)

**做法 2:用 Width Constraint(简单)**
- 不画 spline,直接在草图里画**两个矩形** + **两个圆弧**,M 是 4 个独立几何拼的:
  - 左腿:矩形 (-12.0, -9) → (-8.5, 0),长 19mm 宽 3.5mm
  - 左拱:圆弧从 (-8.5, 0) 弯到 (-3.6, 9),半径 ≈ 10
  - 中 V:三角形 / 圆弧拼,顶点 (0, -2)
  - 右拱、右腿:镜像左半

教程主推**做法 1**(平滑好看),但**做法 2 更适合新手**。

**步骤 5:验证闭合**
- 工具栏 `Validate sketch`(对勾图标)
- 草图必须**闭合**(否则无法 Pad 拉伸)
- 红线 = 缺约束(可选,新手不强制)

### 2.3 拉伸成 3D

1. 退出 Sketcher(点 `Leave sketch` 或 `Done`)
2. 选中刚才的 sketch
3. 工具栏 `Pad` 工具
4. 长度: `1.2 mm`(跟 `FRONT_T` 匹配,黄色区域厚度)
5. 方向:对称(默认向上)
6. OK → 现在你有一个 24×18×1.2mm 的 M 标志 3D 模型

### 2.4 导出 STL

1. 选中 Body(或 Pad)
2. **菜单 → File → Export...**
3. 格式选 `STL mesh (.stl)`
4. 命名:`mc_light_monitor_front_M.stl`
5. 路径:`/home/leonbook5/IdeaProjects/agentspace/mc-light/hardware/`
6. **替换**已有文件(可以先备份: `cp ... .../mc_light_monitor_front_M.stl.bak`)
7. **Export → 选 ASCII 或 Binary**(Binary 体积小 4-5 倍,推荐)

### 2.5 验证 STL 尺寸

```bash
# conda 装 trimesh
conda install -c conda-forge trimesh
# 或 pip
pip install trimesh

# 检查尺寸
python3 -c "
import trimesh
m = trimesh.load('/home/leonbook5/IdeaProjects/agentspace/mc-light/hardware/mc_light_monitor_front_M.stl')
b = m.bounds
print(f'宽: {b[1][0]-b[0][0]:.2f}mm  (期望 24)')
print(f'高: {b[1][1]-b[0][1]:.2f}mm  (期望 18)')
print(f'厚: {b[1][2]-b[0][2]:.2f}mm  (期望 1.2)')
"
```

## 3. 方法 B:Blender(更直观)

### 3.1 启动 + 设单位

```bash
blender  # 或 blender file.blend 后台
```

**关键设置(改 STL 默认单位到 mm)**:
- 菜单 `Edit → Preferences → Scenes → Unit Scale`
- Length: `Millimeters`
- 关闭 `Separate Units` 改 `Metric`
- 这是 Blender 4.x 改单位的地方,不同版本路径可能略不同

### 3.2 画 M 标志

**方法 1(新手):用 SVG 导入**

1. 浏览器打开 https://en.wikipedia.org/wiki/McDonald%27s
2. 找一个 SVG 格式的 M logo(右键 → 另存为 → `.svg`)
3. Blender:`File → Import → Scalable Vector Graphics (.svg)`
4. 选刚才的 svg
5. SVG 会作为 Curve 导入,**编辑模式**(Tab) 选中所有顶点,`S` 缩放到 24mm 宽
6. **Properties → Object Data → Geometry → Extrude: 0.0012**(1.2mm 厚,单位 Blender 内部是 m,所以写 0.0012)

**方法 2(进阶):用 Grease Pencil / Bézier 画**

1. 删默认 cube
2. `Add → Curve → Bézier`
3. Tab 进入编辑模式
4. 像 FreeCAD 那样画 7 个控制点(同 §2.2 的 P1..P7 坐标)
5. 闭合:`右键 → Toggle Cyclic` 或菜单 `Curve → Make Cyclic`
6. **Object Data Properties → Geometry → Extrude: 0.0012 m**

**方法 3(老手):用 Python 脚本(对应 generate_m_shell.py 思路)**

在 Blender 的 Scripting 工作台:

```python
import bpy
import math

# 清空场景
bpy.ops.object.select_all(action='SELECT')
bpy.ops.object.delete()

# 7 个控制点(单位 m,因为 Blender 内部是 m)
scale = 0.001  # 1mm = 0.001 m
P = {
    'P1': (-12*scale, -9*scale, 0),
    'P3': (-3.6*scale, 9*scale, 0),
    'P5': (-3.6*scale, -2*scale, 0),
    'P2': (0, -2*scale, 0),
    'P6': (3.6*scale, -2*scale, 0),
    'P4': (3.6*scale, 9*scale, 0),
    'P7': (12*scale, -9*scale, 0),
}

# 创建 Bézier 曲线
curve_data = bpy.data.curves.new('M_Curve', type='CURVE')
curve_data.dimensions = '2D'
spline = curve_data.splines.new(type='BEZIER')

# 7 个点
points = ['P1', 'P3', 'P2', 'P4', 'P7']  # M 的中线(简化)
spline.bezier_points.add(len(points) - 1)
for i, name in enumerate(points):
    bp = spline.bezier_points[i]
    bp.co = P[name]
    bp.handle_type_left = 'AUTO'
    bp.handle_type_right = 'AUTO'

# 闭合
spline.use_cyclic = True

# 挤出 1.2mm 厚
curve_data.extrude = 1.2 * scale

# 加到场景
obj = bpy.data.objects.new('M_Logo', curve_data)
bpy.context.collection.objects.link(obj)
```

F3 搜 `export` → `STL` → 选这个对象导出。

### 3.3 导出 STL

1. 选中 M 对象
2. `File → Export → Stl (.stl)`
3. **Transform → Scale: 1.0**(不要乱改)
4. **Geometry → Export: Selected Objects**(只导出 M,不要 cube 等)
5. 文件名:`mc_light_monitor_front_M.stl`
6. 覆盖 `~/IdeaProjects/agentspace/mc-light/hardware/` 原文件

## 4. 用 Blender 切片预览(可选)

如果你要送到 3D 打印机,**强烈建议**用 Blender 的切片插件预览:

1. Blender: `Edit → Preferences → Add-ons`
2. 搜索 `切片` 或 `PrusaSlicer` 之类的 addon,启用
3. 选中 M 对象 → 切片预览
4. 检查:
   - 壁厚 ≥ 0.8mm(0.4mm 喷嘴最小)
   - 桥接无悬空 > 5mm
   - 整体能放进 38×38mm 灯盒(留 7mm 边距)

或者用 **Bambu Studio** / **PrusaSlicer** / **Cura** 直接打开 STL,更专业。

## 5. 跟原 Python 脚本的关系

### 5.1 不需要改 `generate_m_shell.py`

这份教程**不让你改** `generate_m_shell.py`,**只让你替换 STL**。理由:
- `generate_m_shell.py` 是**参数化生成器**,改参数要重装 Python 依赖(shapely, trimesh, manifold3d)
- 手工 FreeCAD/Blender 画出来的 M 更"手工调",适合一次性修正
- 维护 2 套 M 来源(程序 + 手工)比只保留 1 套手工的更灵活

### 5.2 如果你以后想回到程序化路线

新 M 的参数可以是:
- `M_WIDTH = 24.0`(不变)
- `ARCH_R = 7.0`(原 6.0,稍大)
- `LEG_H = 10.0`(原 12.0,稍短)→ `M_HEIGHT = 17.0`
- `M_WIDTH / M_HEIGHT` = 1.41(更接近真标 1.3~1.5)

要改,改 `hardware/generate_m_shell.py` 的 4 个参数(行 43-46),重跑:
```bash
cd ~/IdeaProjects/agentspace/mc-light/hardware
python3 generate_m_shell.py
```

**但** 调整贝塞尔曲线的 12 个控制点(行 102-130)更关键 — 那是 M "好不好看"的灵魂。新手改控制点会乱,推荐 FreeCAD 手工。

## 6. 验收清单

导出新 STL 后,**强制**过这些检查:

```bash
# 1. 尺寸对吗
python3 -c "
import trimesh
m = trimesh.load('/home/leonbook5/IdeaProjects/agentspace/mc-light/hardware/mc_light_monitor_front_M.stl')
b = m.bounds
w = b[1][0]-b[0][0]
h = b[1][1]-b[0][1]
t = b[1][2]-b[0][2]
print(f'宽 {w:.2f}mm 期望 24.0 ±0.5')
print(f'高 {h:.2f}mm 期望 18.0 ±0.5  (重要!原来 21.5 太瘦)')
print(f'厚 {t:.2f}mm 期望 1.2 ±0.1')
print(f'宽高比: {w/h:.2f} 期望 1.30~1.50')
assert 23.5 <= w <= 24.5, '宽度不在 24±0.5'
assert 17.5 <= h <= 18.5, '高度不在 18±0.5'
assert 1.1 <= t <= 1.3, '厚度不在 1.2±0.1'
assert 1.30 <= w/h <= 1.50, '宽高比不对'
print('✅ 全部通过')
"
```

如果通过,新 M 标志就**几何合规**。然后:
1. **视觉验收**:在 FreeCAD/Blender 里转一圈,看 M 像不像
2. **打印验证**:送切片软件看能不能印
3. **装上灯盒看效果**:打印出来后,装上 XIAO RP2040,通电看 M 透光效果

## 7. 故障排查

### 7.1 FreeCAD 草图无法 Pad

**症状**:Pad 按钮灰的 / 报错 "Sketch is not closed"

**解**:
- 选草图 → 编辑 → 看有没有"开口"(红线)
- 闭合:用 `Create line` 工具手动把最后一点连回第一点
- 或者 spline 末点右键 → `Make cyclic`

### 7.2 Blender 单位错了

**症状**:导出 STL 后尺寸是 24 米而不是 24mm

**解**:
- `Scene Properties → Units → Unit Scale = 0.001`
- 或 Transform → Apply Scale 1.0
- 改完**重新导出**

### 7.3 STL 表面有破洞

**症状**:切片软件报错 "non-manifold edges"

**解**:
- FreeCAD:用 `Part → Refine shape` 修复
- Blender:进入编辑模式 → `Mesh → Clean up → Merge by Distance`(0.0001)
- 实在不行,导出时勾 `Apply modifiers`

### 7.4 M 看起来不对(瘦 / 胖 / 歪)

**调整坐标**:
- 太瘦 → 把 P3 / P4 的 y 减小(从 9 → 7)
- 太胖 → 把 P1 / P7 的 y 增大(从 -9 → -10)
- 拱太尖 → P3 / P4 的 y 减小,或拉 spline 控制柄
- 脚太长 → P1 / P7 的 y 减小(从 -9 → -7)
- 改完重画,回到 §6 跑验收

## 8. 推荐学习路径(小白)

1. **第 1 天**:FreeCAD Part Design 入门
   - 官方教程:https://wiki.freecad.org/Part_tutorial
   - 跟着画个立方体+倒角,**会了再回来**
2. **第 2 天**:FreeCAD Sketcher 画二维
   - 教程:https://wiki.freecad.org/Sketcher_tutorial
   - 画几个矩形、圆、B-spline
3. **第 3 天**:本教程 §2.1-2.4,画第一个 M,导出
4. **第 4 天**:切片 + 打印(可选,先电子版验)
5. **后续**:用 Blender 改 / 优化,做动画版 M(可选)

**总投入**:**2-4 小时**能完成第一个新 M 标志(纯软件验证),打印出来 + 装灯 + 通电看效果再 +1-2 天(含等打印)。

## 9. 致谢

这份教程参考了:
- McDonald's 品牌规范(公开资料)
- FreeCAD 官方 Sketcher 教程
- Blender 4.x 手册
- 你原 `hardware/generate_m_shell.py` 的几何参数(了解灯盒尺寸上下文)

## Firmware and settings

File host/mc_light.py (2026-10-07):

"""mc-light host hook script: send on/off over USB serial to the XIAO RP2040.

跨平台:
- Windows:纯标准库(winreg 枚举 COM 口 + ctypes 写串口),零 pip 依赖。
- 其它平台(含 WSL/Ubuntu):回退到 pyserial。
"""
import os
import re
import sys

IS_WINDOWS = sys.platform == "win32"

if not IS_WINDOWS:
    import serial
    from serial.tools import list_ports

# 兼容两种 XIAO RP2040:Raspberry Pi 官方 VID 与 Seeed 自家 VID
XIAO_VIDS = (0x2E8A, 0x2886)

# 环境变量:显式指定 COM 口(Windows)/ttyACM(Ubuntu),绕过自动识别
ENV_PORT = "MC_LIGHT_PORT"


def _parse_mi(text):
    """从 hwid/location 文本提取 USB 接口号(MI_xx 或 LOCATION 尾段)。

    CircuitPython 的 boot.py 打开 console + data 两路 CDC:
    console 占用接口 0, data 占用接口 2(Windows 表现为 MI_00 / MI_02)。
    接口号越大越可能是 data 口。返回 None 表示拿不到。
    """
    m = re.search(r"MI_(\d+)", text, re.IGNORECASE)
    if m:
        return int(m.group(1))
    m = re.search(r"&0&(\d+)$", text)
    if m:
        return int(m.group(1))
    return None


def _select_data_port(matches):
    """从 VID 已过滤的候选端口里挑 data 口。`matches` 元素需具备
    .device/.description/.interface/.hwid/.location 属性(模拟 pySerial 对象)。

    优先级:
      1. description/interface 含 "CDC2"/"data" 的口(直连判断)。
      2. 按 USB 接口号(MI_xx)取最大——data 口接口号大于 console。
      3. 都无法区分时返回 None,绝不猜。
    绝不按 device 字符串排序:Windows COM 号不保证顺序(COM9 < COM10)。
    """
    if not matches:
        return None
    for p in matches:
        desc = (p.description or "") + " " + (p.interface or "")
        if "CDC2" in desc or "data" in desc.lower():
            return p.device
    with_mi = [(p, _parse_mi(" ".join(str(x or "") for x in (p.hwid, p.location))))
               for p in matches]
    known = [(p, mi) for p, mi in with_mi if mi is not None]
    if known:
        return max(known, key=lambda kv: kv[1])[0].device
    return None


def _find_light_port_generic():
    """非 Windows 路径:用 pyserial 枚举,再交 _select_data_port 判定。"""
    explicit = os.environ.get(ENV_PORT)
    if explicit:
        return explicit

    matches = [p for p in list_ports.comports() if p.vid in XIAO_VIDS]
    return _select_data_port(matches)


if IS_WINDOWS:
    # ------------------------------------------------------------------
    # Windows 零依赖路径
    # ------------------------------------------------------------------
    import ctypes
    import ctypes.wintypes as wt
    import winreg

    kernel32 = ctypes.WinDLL("kernel32", use_last_error=True)
    kernel32.CreateFileW.restype = wt.HANDLE
    kernel32.CreateFileW.argtypes = [wt.LPCWSTR, wt.DWORD, wt.DWORD, wt.LPVOID,
                                     wt.DWORD, wt.DWORD, wt.HANDLE]
    kernel32.WriteFile.argtypes = [wt.HANDLE, wt.LPVOID, wt.DWORD,
                                   ctypes.POINTER(wt.DWORD), wt.LPVOID]
    kernel32.SetCommTimeouts.argtypes = [wt.HANDLE, wt.LPVOID]
    kernel32.EscapeCommFunction.argtypes = [wt.HANDLE, wt.DWORD]
    kernel32.CloseHandle.argtypes = [wt.HANDLE]

    GENERIC_READ = 0x80000000
    GENERIC_WRITE = 0x40000000
    OPEN_EXISTING = 3
    FILE_ATTRIBUTE_NORMAL = 0x80
    SETDTR = 5
    CLRDTR = 6
    INVALID_HANDLE = ctypes.c_void_p(-1).value

    class _COMMTIMEOUTS(ctypes.Structure):
        _fields_ = [("ReadIntervalTimeout", wt.DWORD),
                    ("ReadTotalTimeoutConstant", wt.DWORD),
                    ("ReadTotalTimeoutMultiplier", wt.DWORD),
                    ("WriteTotalTimeoutConstant", wt.DWORD),
                    ("WriteTotalTimeoutMultiplier", wt.DWORD)]

    _VID_RE = re.compile(r"VID_([0-9A-Fa-f]{4})")
    _MI_RE = re.compile(r"MI_(\d+)", re.IGNORECASE)

    def _enumerate_usb_ports():
        """枚举注册表 Enum\\USB 下所有 VID/PID 设备实例,返回 pySerial 风格对象列表,
        每项带 .device/.vid/.description/.interface/.hwid/.location。
        """
        from types import SimpleNamespace
        base = r"SYSTEM\CurrentControlSet\Enum\USB"
        results = []
        try:
            root = winreg.OpenKey(winreg.HKEY_LOCAL_MACHINE, base)
        except OSError:
            return results
        try:
            for i in range(winreg.QueryInfoKey(root)[0]):
                sub = winreg.EnumKey(root, i)
                sub_path = base + "\\" + sub
                # 递归一层:USB\<VID&PID>\<实例>\Device Parameters\PortName
                try:
                    inst = winreg.OpenKey(winreg.HKEY_LOCAL_MACHINE, sub_path)
                except OSError:
                    continue
                try:
                    for j in range(winreg.QueryInfoKey(inst)[0]):
                        inst_name = winreg.EnumKey(inst, j)
                        inst_path = sub_path + "\\" + inst_name
                        port = None
                        try:
                            pp = winreg.OpenKey(winreg.HKEY_LOCAL_MACHINE,
                                                inst_path + r"\Device Parameters")
                            try:
                                port, _ = winreg.QueryValueEx(pp, "PortName")
                            finally:
                                winreg.CloseKey(pp)
                        except OSError:
                            pass
                        if port is None:
                            continue
                        try:
                            k = winreg.OpenKey(winreg.HKEY_LOCAL_MACHINE, inst_path)
                            try:
                                hwids, _ = winreg.QueryValueEx(k, "HardwareID")
                                try:
                                    desc, _ = winreg.QueryValueEx(k, "FriendlyName")
                                except OSError:
                                    desc = ""
                            finally:
                                winreg.CloseKey(k)
                        except OSError:
                            hwids = []
                            desc = ""
                        hwid0 = hwids[0] if hwids else ""
                        m = _VID_RE.search(hwid0 or sub)
                        vid = int(m.group(1), 16) if m else None
                        mi = _MI_RE.search(hwid0)
                        mi_n = int(mi.group(1)) if mi else _parse_mi(hwid0)
                        results.append(SimpleNamespace(
                            device=port,
                            vid=vid,
                            description=desc or "USB Serial Device (%s)" % port,
                            interface=None,
                            hwid=hwid0,
                            location="",
                            _mi=mi_n,
                        ))
                finally:
                    winreg.CloseKey(inst)
        finally:
            winreg.CloseKey(root)
        return results

    def find_light_port(vids=XIAO_VIDS):
        """Windows 路径:枚举注册表 COM 口,VID 过滤 + _select_data_port 判定。"""
        explicit = os.environ.get(ENV_PORT)
        if explicit:
            return explicit

        matches = [p for p in _enumerate_usb_ports()
                   if p.vid is not None and p.vid in vids]
        return _select_data_port(matches)

    def send_command(port, byte, timeout=1.0):
        """Windows 路径:ctypes 打开 COM 口写单字节。`byte` 为单字节 bytes。"""
        path = "\\\\.\\" + port
        h = kernel32.CreateFileW(path, GENERIC_READ | GENERIC_WRITE, 0, None,
                                 OPEN_EXISTING, FILE_ATTRIBUTE_NORMAL, None)
        if h == INVALID_HANDLE:
            raise OSError(ctypes.get_last_error(), f"open {port} failed")
        try:
            to = _COMMTIMEOUTS(100, 100, 0, int(timeout * 1000), 0)
            kernel32.SetCommTimeouts(h, ctypes.byref(to))
            kernel32.EscapeCommFunction(h, SETDTR)
            wbuf = ctypes.create_string_buffer(byte)
            n = wt.DWORD(0)
            ok = kernel32.WriteFile(h, wbuf, 1, ctypes.byref(n), None)
            if not ok:
                raise OSError(ctypes.get_last_error(), f"write {port} failed")
            if n.value != 1:
                raise OSError(f"write {port}: only {n.value} byte written")
        finally:
            try:
                kernel32.EscapeCommFunction(h, CLRDTR)
            finally:
                kernel32.CloseHandle(h)

else:
    find_light_port = _find_light_port_generic


COMMANDS = {"on": b"1", "off": b"0", "wait": b"2"}


def main(argv=None):
    argv = argv if argv is not None else sys.argv[1:]
    if not argv or argv[0] not in COMMANDS:
        return 0
    debug = os.environ.get("MC_LIGHT_DEBUG") == "1"
    try:
        port = find_light_port()
        if port is None:
            if debug:
                print("mc-light: 未找到 XIAO RP2040 串口", file=sys.stderr)
            return 0
        send_command(port, COMMANDS[argv[0]])
    except Exception as e:
        # 作为 hook 被调用时不要吵闹地失败;设 MC_LIGHT_DEBUG=1 可以打印错误定位问题。
        if debug:
            print(f"mc-light: {type(e).__name__}: {e}", file=sys.stderr)
    return 0


if __name__ == "__main__":
    sys.exit(main())

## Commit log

2026-07-17 fix: harden main() error guard, fix README python3, robust test import
    [mc_light.py]
2026-07-17 feat(hardware): add parametric M-lightbox + base STL generator
    生成金拱门 M 光盒 + 桌面底座的 3D 打印模型:
    - generate_m_shell.py: 参数化网格生成脚本 (trimesh)
    - mc_light_M.stl: M 光盒 (前面板+侧壁,背面开口),平躺打印
    - mc_light_base.stl: 桌面底座 (插槽+内腔+USB出线口)
    - mc_light_assembled.stl: 组装预览
    [mc_light_M.stl, mc_light_assembled.stl, mc_light_base.stl]
2026-07-18 docs: design monitor-side xiao case
2026-07-18 docs: plan monitor-side xiao case
2026-07-19 feat: generate monitor-side xiao case
    Replace the desktop-base M lightbox generator with a monitor-side
    square case for Seeed XIAO RP2040: flat-back shell with a bottom
    USB-C opening and internal board rails, plus a split flush translucent
    red/yellow M front cover for multi-color printing. Old M lightbox +
    desktop base STLs and stale preview removed.
    Deviation from plan: the rail_z formula (WALL_T + BOARD_POCKET_H/2)
    made the limiting rails protrude past the shell front (13.2 > BACK_D
    12.8) and broke the sz≈BACK_D test; corrected to
    WALL_T + BOARD_RAIL_H/2 so rails sit on the inner back wall.
    [mc_light_M.stl, mc_light_assembled.stl, mc_light_base.stl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]
2026-07-19 test: cover monitor case generator geometry
    Add tests for front-cover flush/thin geometry, square face size, back
    shell bottom USB opening + XIAO clearance, assembly depth, and the
    exported STL file name list.
2026-07-19 docs: document monitor-side case printing
    Update README hardware section to describe the monitor-side box,
    two-part structure, split front STL files, and bottom-up USB-C
    insertion. Mark the implementation plan complete with a note on the
    rail_z correction and the pre-existing host test failure.
2026-07-19 test: fix host port mock and cover CDC2 selection
    The _port() test helper only set vid/device, but find_light_port reads
    description/interface for CDC2/data selection, so the matching-device
    test raised AttributeError. Add those fields (default "") and a test
    for the CDC2 priority path.
2026-08-17 docs: 麦当劳 M 标志重新设计教程(从零用 FreeCAD/Blender)
    不修改现有硬件 STL 和 generate_m_shell.py,只提供一份
    小白友好的教程,教用户从零手工画一个比例更接近真标的
    M 标志,然后替换 mc_light_monitor_front_M.stl。
    教程内容:
    - 现状分析: 当前 M 24x21.5x1.2mm,宽高比 1.12 (太瘦)
    - 目标尺寸: 24x18x1.2mm,宽高比 1.33 (更接近真标 1.3~1.5)
    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
2026-08-20 Redesign M shell as McDonald's-style logo
    - Rewrite m_polygon() to generate an outlined McDonald's-style M using
    cubic Bézier arches and stroke buffering instead of the previous
    filled curve.
    - Add geometry tests validating logo proportions and foot placement.
    - Regenerate front/assembled STL models and add 3MF/gcode exports plus
    a reference logo image.
    [mc_light_monitor_assembled.stl, mc_light_monitor_front_M.3mf, mc_light_monitor_front_M.gcode.3mf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]
